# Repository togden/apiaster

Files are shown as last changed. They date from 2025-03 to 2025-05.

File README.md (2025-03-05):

# Apiaster

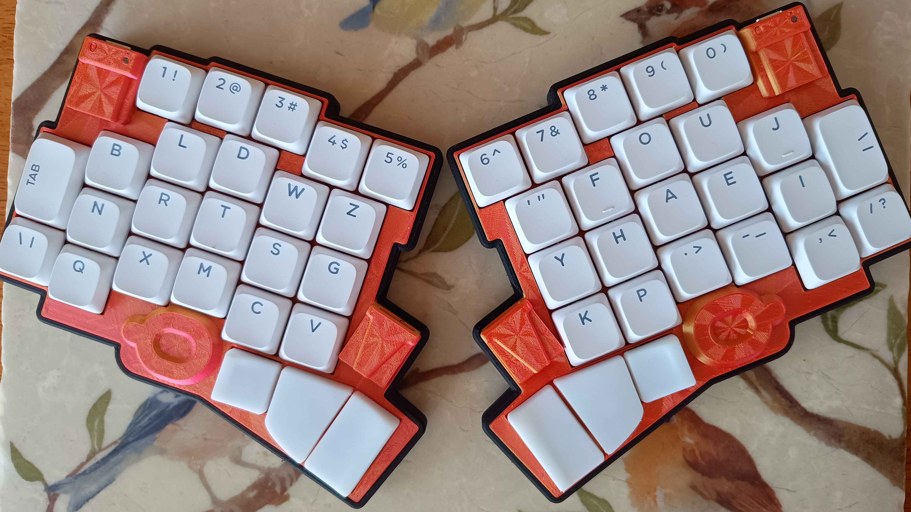
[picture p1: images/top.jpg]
Apiaster Title Image

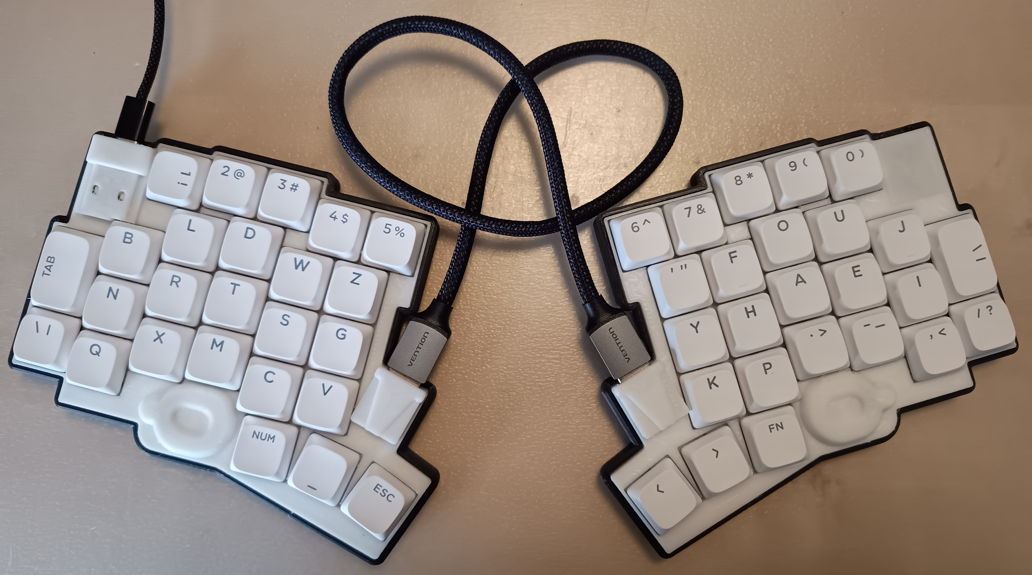
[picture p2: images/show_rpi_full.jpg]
Image of Apiaster in white and black, using rp2040-zero connected by cable.

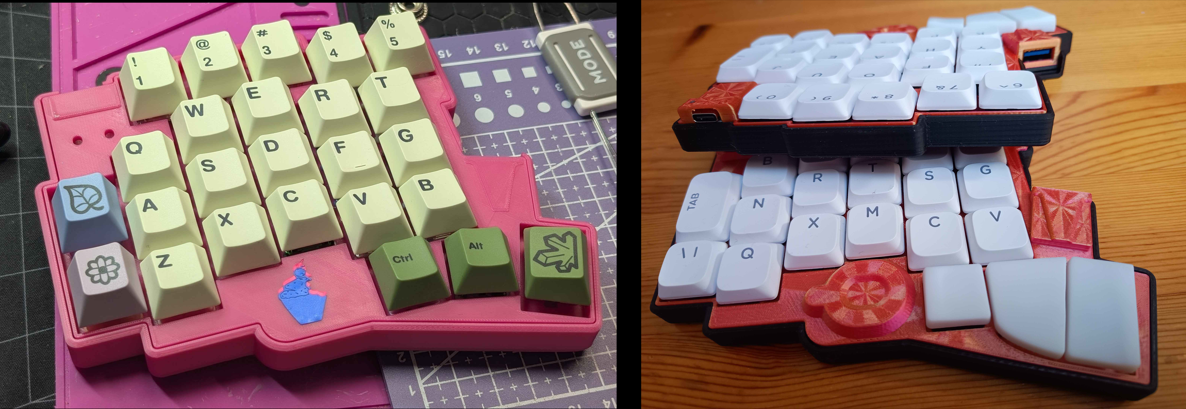
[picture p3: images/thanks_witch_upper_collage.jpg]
Two images side by side, one with Apiaster from the top, the other MX thanks to Witch

Apiaster is a 50-key split keyboard with both an MX and a Kailh choc (v1 & v2) version. It is designed with price and flexibility in mind. The Apiaster is named after the [European bee-eater](https://en.wikipedia.org/wiki/European_bee-eater). Apiaster runs [ZMK firmware](https://zmk.dev/), with the customisation of keymaps, layers, and behaviors allowing it to output every key present in a 108-key 100% keyboard *and more*. **In its most basic form, Apiaster can be built for a total of $36.35 in parts, not including shipping/tariffs/customs or tooling. A version costing $39.11 can be "upgraded" with additional features such as Bluetooth over time.**

# Motivation

There are a number of reasons why someone might be interested in a split, column-staggered[^1] keyboard such as the Apiaster. Most commonly, ergonomics and comfort. Ergonomics is something that tends to be specific to each individual though, making selecting such a keyboard difficult. Both individuals lost for choice and individuals who have amassed a collection of three or more keyboards in the search for their perfect ergonomic experience are not uncommon to see.

Apiaster was designed with flexibility in mind, in particular:
1. The thumb cluster can be snapped off and moved. The case is generated from a script, allowing it to be moved to most reasonable locations (as long as it doesn't collide with the rest of the PCB).
2. The optional choice of reduced inner keys, reducing the strain on the index fingers by avoiding some particularly uncomfortable keys (B and N in a QWERTY layout).
3. The optional choice of an [alternative thumb cluster](https://github.com/Nick-Munnich/ripple-thumb-keycaps) I designed, which brings the thumb keys closer together than would be possible with standard keycaps.

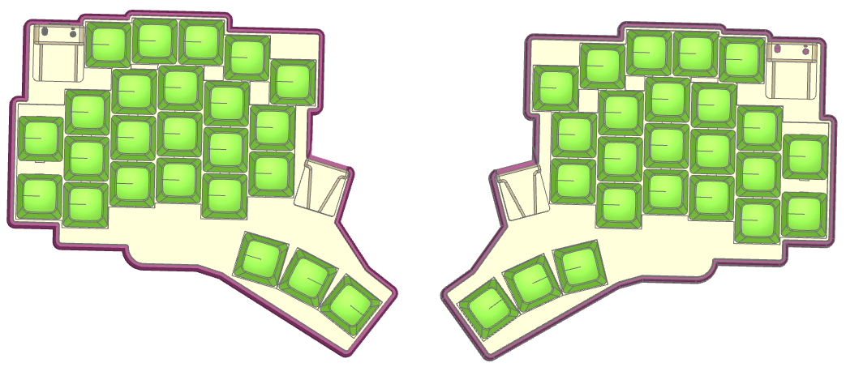
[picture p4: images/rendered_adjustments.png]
Image of a rendered case with adjustments
|  | 
|:--:| 
| *Render showing some of these adjustments* |

This extra flexibility allows individuals to tune the Apiaster to their liking, either providing them with a suitable "endgame" or allowing them to narrow down what specific layout they want quicker. 

## Price

Cost is one of the biggest barriers to entry for ergo-split keyboards. A set of keycaps and switches alone costs more than a cheap basic membrane keyboard. Commercial offerings tend to be either expensive or unreliable. To reduce this barrier to entry, Apiaster is flexible once more:

1. The MCU can be a single rp2040-zero (around 2-3$) with both halves connected via a wire, a single Seeed Studio XIAO (either rp2040 or nrf52840, the latter of which allows the keyboard to have BLE), or a pair of Seeed Studio XIAO nRF52840's (Fully wireless keyboard, no wire between halves).

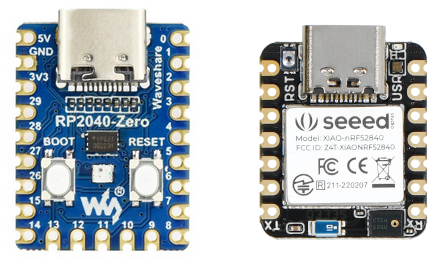
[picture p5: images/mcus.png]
mcu options
|  | 
|:--:| 
| *RP2040-Zero on the left, XIAO nRF52840 on the right* |

3. There are options for both MX and Choc switches, albeit with different PCBs. MX switches are high profile and cheap, with lots of options. Choc switches are low profile and pricier.

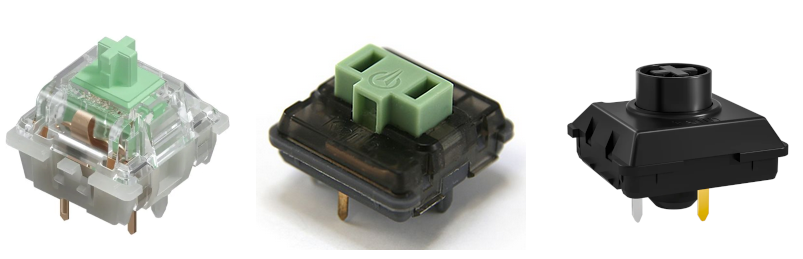
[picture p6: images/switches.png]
switch options
|  | 
|:--:| 
| *MX (18mm), Choc v1 (10.6mm), Choc v2 (12mm) in that order.* |

4. The PCB itself is designed to be reversible, reducing ordering costs from PCB manufacturers (these have a min order number of 5 PCBs).
5. Apiaster can be powered (on wireless) via either a LiPo battery (more capacity, difficult to source reliably) or from a rechargeable coin cell battery

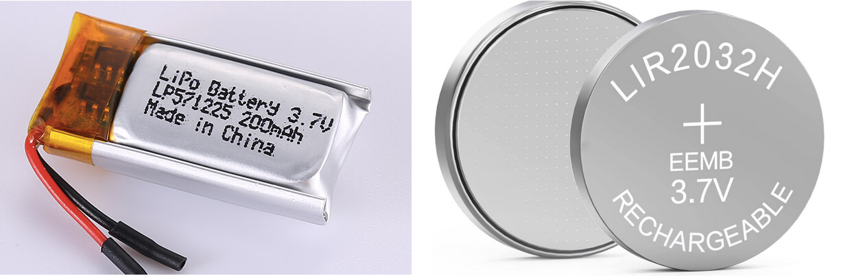
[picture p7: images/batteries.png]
battery options
|  | 
|:--:| 
| *LiPo on the left, coin cell on the right. The ordering guide informs you of dimensional constraints for a LiPo battery.* |

## Mouse

With a split-ergo keyboard, reduced mouse usage is common, and some go so far as to build a pointing device such as a trackball or a trackpad into their keyboard. In theory, Apiaster *should* also have this capability (on the right hand side only, when used via Bluetooth only). However, this is currently untested and lacks case adjustments as I do not have the hardware to implement and test such a pointing device. 

[^1]: The number row is also row-staggered, this will be discussed in the next section.

# Ergonomics

Keyboard ergonomics is a complex topic. There is a lack of research in the particular topic of how beneficial a split keyboard actually is, despite plenty of individuals claiming their benefits - it is simply difficult to get the necessary participants and dedication to such a research study. Moreover, everything in the body is linked - some may find it more beneficial to get a more suitable chair, or a desk at a different height.

Without going into too much detail, I want to provide a brief overview of what is now commonly agreed upon, and how some of the design decisions of this keyboard were made as a consequence. A read of [this page](https://ergonomictrends.com/proper-ergonomic-typing-posture-at-computer/) can be a good introduction to some good typing habits.

## Why Split

There are multiple benefits to a fully split keyboard, i.e. one that consists of two completely separated halves. The obvious intuitive reason is that you can dedicate one half to each hand, but let's explore the rabbit hole a bit, shall we? 

For long-term comfortable typing, a [neutral wrist position](https://ergonomictrends.com/types-of-wrist-movements-and-injuries/) is preferred. Not a *perfectly* neutral position, at least not for most people, but a comfortably neutral position. 

Your shoulders are on the side of your torso. If your keyboard is directly in front of you and you try to place your hands in line with your keyboard, then you cause ulnar deviation. Most people who learned to type naturally, i.e. were not taught bad typing habits in a classroom, will have their hands at an angle to their keyboard when at rest. It makes sense to angle the keys that each hand uses towards them, to bring the keyboard in line with your arm and hand movement, encouraging a neutral wrist.

While there exist many designs for unibody keyboards which have angles between halves dedicated to each hand (e.g. the [ffkb](https://fingerpunch.xyz/product/faux-fox-keyboard-v4/)), a true split allows for every individual to angle the halves at whichever angle and distance is most comfortable to them. The angle at which you want your keyboard and how close you want the halves to be is related to how far away you want it from your torso.

### Tenting

Fully split keyboards also allow for [tenting](https://www.reddit.com/r/ErgoMechKeyboards/comments/1i2s2or/magsafe_is_the_most_underrated_tenting_solution/). This prevents over rotation of the wrist, allowing for a more neutral position. The ideal tenting angle is again, dependant on the individual and the distance at which the keyboard is from the user. 

### Other Benefits

Aside from the above ergonomic benefits, split keyboards are also just nice to have for some other, miscellaneous reasons. They free up space in the middle of your desk, perfect for a mug or a glass or especially for a cat that used to love lying on your keyboard. You can [mount the halves to your armrests](https://www.reddit.com/r/ErgoMechKeyboards/comments/1if5sec/magsafe_accessories_as_keyboard_mount_on/). While gaming, you can put away one half and free up a ton of room for your mouse. 

## Staggered Keys

Most keyboards commonly used today are "row staggered".

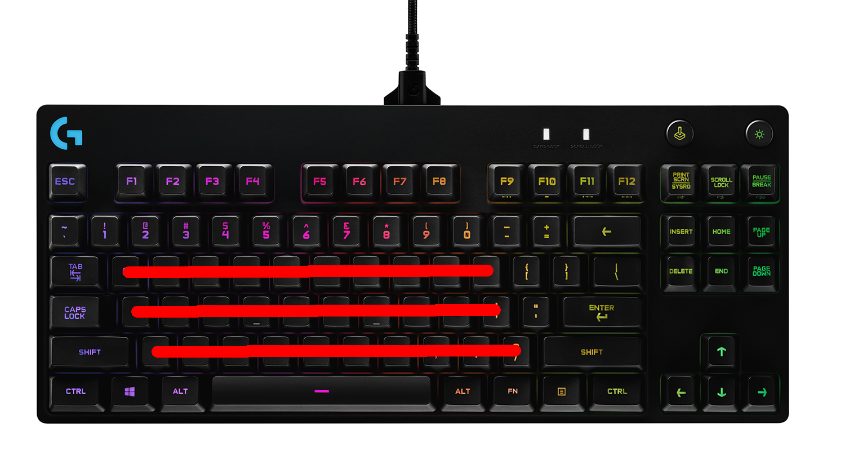
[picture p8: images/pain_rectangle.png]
Row Staggered Keyboard


Row stagger originated with typewriters due to mechanical reasons, and it's just sort of....stayed. Row stagger forces your fingers to move from side to side as they move up and down rows. We can do better.

Column staggered keyboards stagger the keys in line with your fingers.
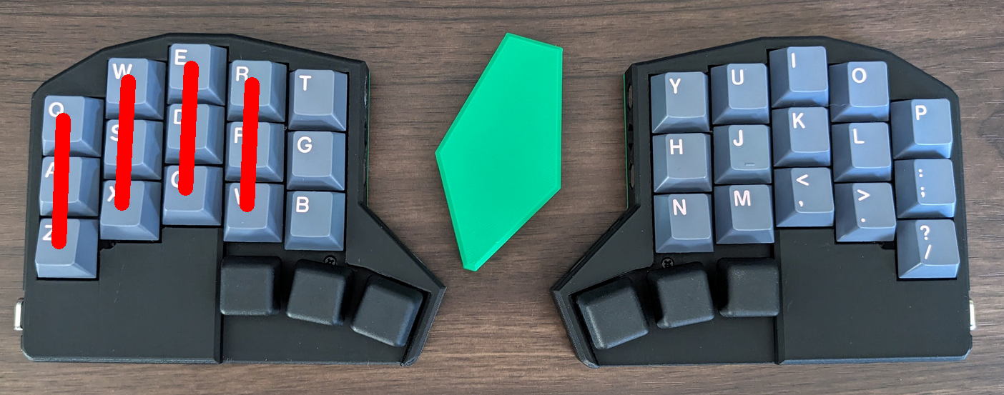
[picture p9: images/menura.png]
Menura
|| 
|:--:| 
| *[Menura](https://github.com/rmuraglia/menura-kb) Keyboard* |

The amount of stagger that is ideal is generally related to the lengths of each finger. Apiaster's stagger is not as mild as the [corne](https://github.com/foostan/crkbd), nor is it as extreme as the [ferris](https://github.com/foostan/crkbd). The ring finger stagger is slightly less than that of the index, making it more suitable for those whose ring finger is longer than their index, at the cost of being less suitable towards those with the opposite.

Some keyboards also introduce what is known as "splay", where the columns are no longer parallel to one another, but splay outwards. This is because for most people, our fingers will naturally splay outwards to some degree as they are stretched. 

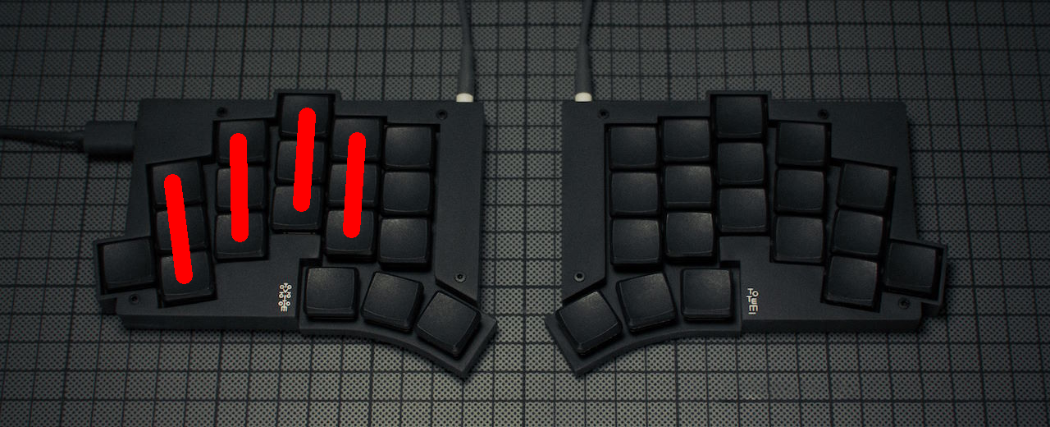
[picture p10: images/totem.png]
Totem
|| 
|:--:| 
| *[Totem](https://github.com/GEIGEIGEIST/TOTEM) Keyboard* |

### Apiaster

Apiaster features column stagger, but it also features a row staggered number row. The inclusion of a number row was desirable primarily because:

1. It is a less extreme drop in keys, making the keyboard more approachable. 
2. A number row is *highly* desirable for gaming. The key count and key positions of Apiaster were selected to be *just above* what I consider to be the minimum keycount desirable for gaming with one hand on the keyboard and the other on the mouse (My personal minimum is 23 keys, dropping one of the outer pinkies and one key from the inner index column).
3. I believe some occasional stretching of the fingers can be beneficial *if* that stretching is in line with the finger's natural path.

The number row was row staggered in addition to being column staggered for two reasons:

1. The pinky being so small for most people, if the number 1 was in line with the column your hand would have to move to reach it (or you would just be pressing it with your ring finger). The outermost upper pinky key is a more suitable place for a fourth pinky than in line with the column.
2. By row staggering the number row, it naturally somewhat imitates finger splay, but only when the fingers are further extended. This is when the splay becomes more obvious for most.

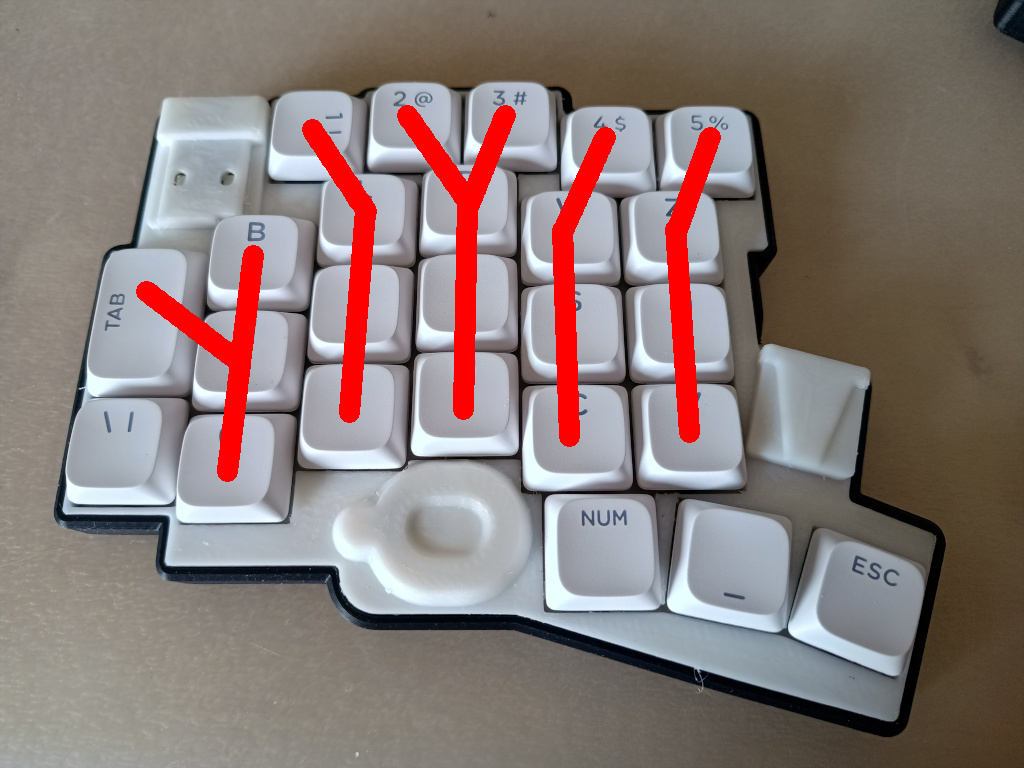
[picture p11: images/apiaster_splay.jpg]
Apiaster's Splay


The specific values chosen for the row stagger also allow the ring and index finger to hit the 2 and 3 without issues, and it happens to closely match the relative stagger of the number row when fingers are resting on WASD on a standard QWERTY keyboard. (Gaming on this keyboard would use the keys labeled DRTS in place of WASD, though the positions matter, not the keyboard layout).

## Thumbs

Thumbs are underused massively with standard keyboards. Ergonomic keyboards will commonly take advantage of their split nature to offer a thumb cluster with more keys than just one.

The thumb cluster is the most difficult part of the keyboard to get right. Variations in hand size, thumb flexibility, etc. can cause wide variations in preferred hand positions. Compare the [corne]() to the [cheapino](https://github.com/tompi/cheapino) for example. The ability of the Apiaster to move the thumb cluster is very advantageous in this respect. There are still some points I wish to touch upon, though.

1. Tucking thumbs under your palm is generally seen as uncomfortable by most. Putting your thumb in line with your index finger is usually the most "inner" position that is still comfortable. Apiaster's minimum is slightly more outer than this.
2. Thumbs move in an arc, not up and down. Hence thumb clusters should do the same. 
3. The thumb cluster is generally recommended to be on the same plane (or a plane parallel to) the other keys. Otherwise you run an increased risk of [De Quervain Syndrome](https://en.wikipedia.org/wiki/De_Quervain_syndrome), a problem that is ever more likely to occur due to increased smartphone usage.
4. Minimizing movement of the thumb along the "fan" is seen as desirable. 

Apiaster is capable of having both standard keycaps at an 11 degree angle between keys or it can use a [thumb cluster](https://github.com/Nick-Munnich/ripple-thumb-keycaps) I designed, which has its own advantages (read the README in the repo) but unfortunately needs to be 3D printed.

# Ordering and Build Guide

The ordering and build guide for this keyboard can be found [here](docs/_START_HERE.md).

# Firmware

Firmware can be found [here](https://github.com/Nick-Munnich/zmk-apiaster-module).

# Acknowledgements and References

There are a number of people and projects which served as inspiration and motivation for this project. Thank you to Sadwitch and tompi (cheapino) for serving as initial inspiration for the concept, and again to Sadwitch for helping with various little bits. Thank you to carrefinho for letting me use some of their art. Thank you to petejohanson and bravekarma for all of their work on ZMK. Thank you to hookykb for writing the charlieplex driver, which this keyboard relies upon. Thank you to quappo for providing the inspiration for the inner key column alternative keys. Finally, thank you to sadekbaroudi and all of the lovely folks on the fingerpunch Discord. Keep being awesome.

Certain images in this README were taken from the websites of manufacturers or vendors and can be taken down on request.

# License

This README and any images which I have the rights to are licensed under CC BY-NC-SA. Individual parts of this repo are licensed under different terms which can be found under their corresponding folders. In particular:

- The hardware stuff found under `/pcb` is licensed under CERN OHL-S.
- The contents of `/case`, in particular the source code used to generate the case, is licensed under MIT.
- The documentation is licensed under CC BY-NC-SA.

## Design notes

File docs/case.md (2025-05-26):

# Generating The Case

You will be running the case generator via GitHub Actions. To do so, start by forking this repository

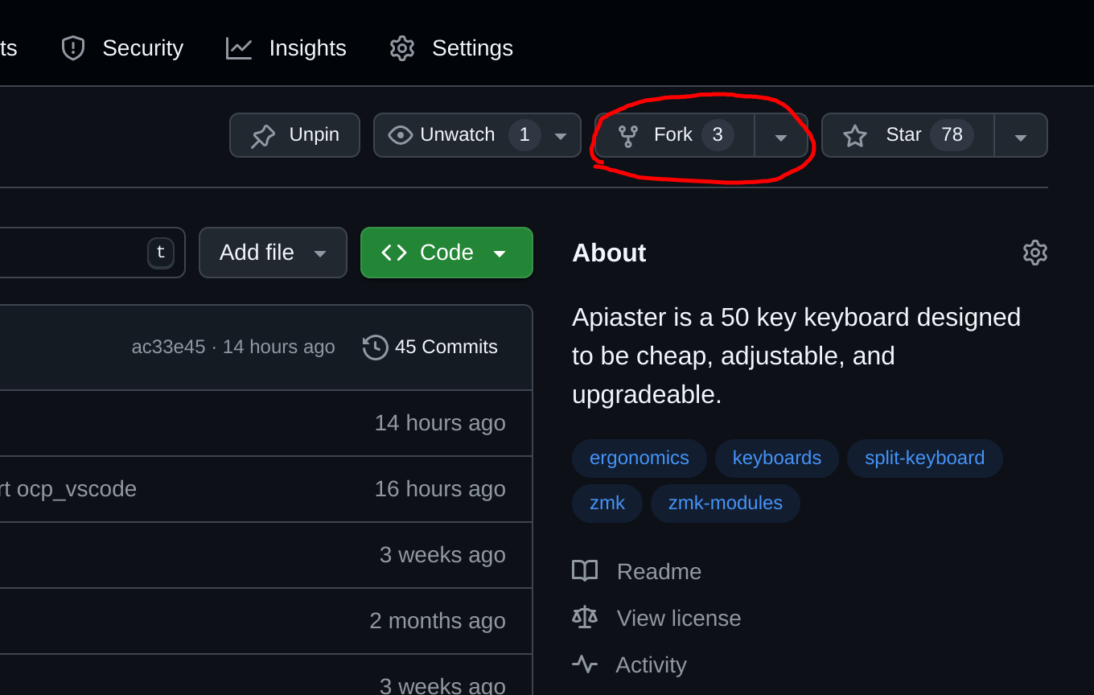
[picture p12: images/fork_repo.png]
Fork the repo


Next, make sure that you have GitHub Actions enabled in your repository. Go to `Settings` and then the Actions (General) category:

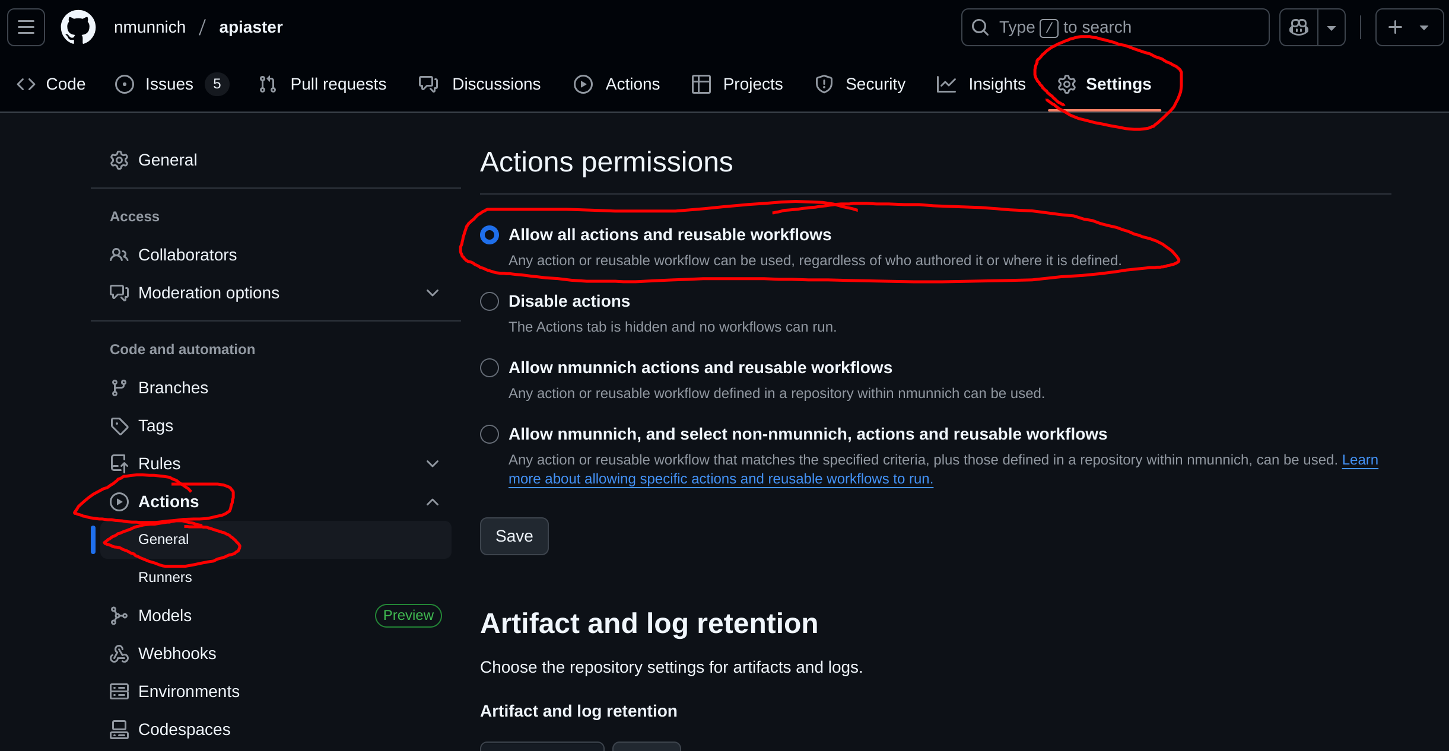
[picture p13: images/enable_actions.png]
Enable GitHub Actions


Make sure "Allow all actions and reusable workflows" is selected (click save!).

Now navigate to the `Actions` tab, and click on the "Make Case" action on the left:

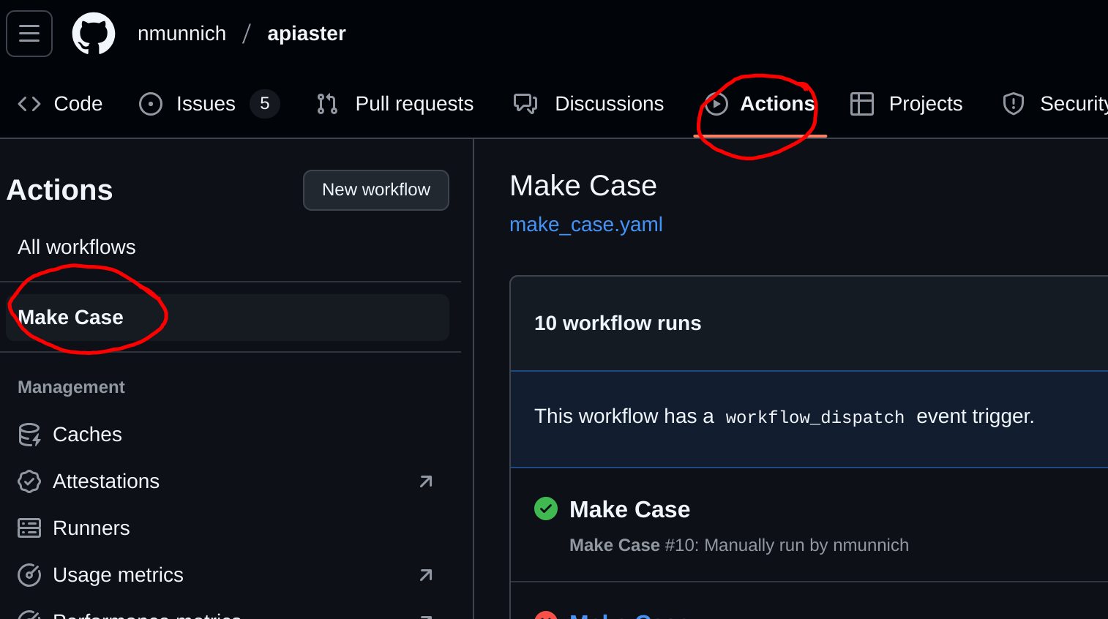
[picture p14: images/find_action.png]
Make Case


You can then click `Run workflow` and adjust any settings you desire, then click `Run workflow` at the bottom.

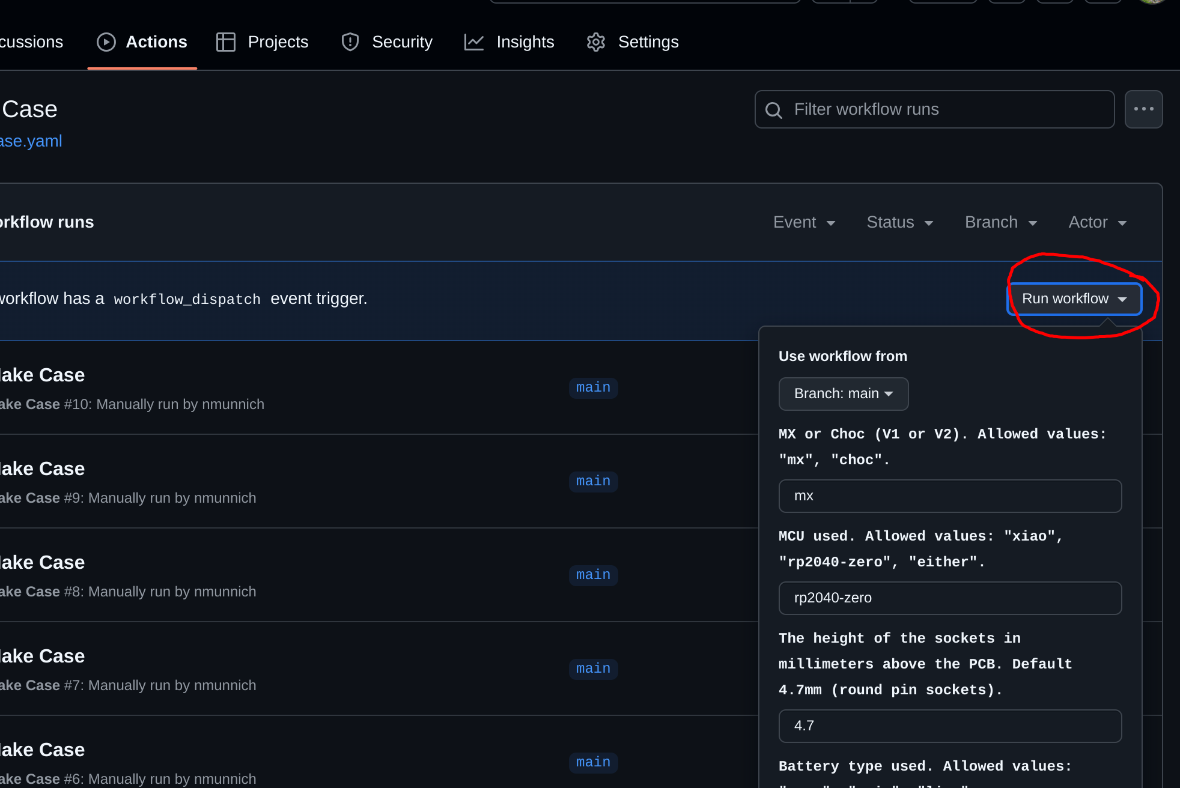
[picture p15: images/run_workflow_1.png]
Run Workflow

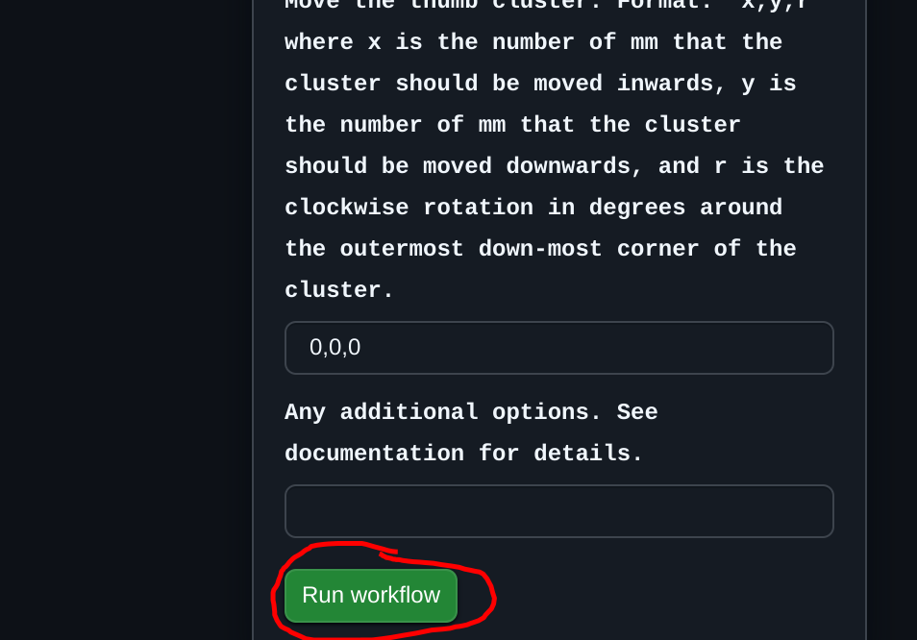
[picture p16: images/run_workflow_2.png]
Run Workflow


After refreshing the page, a new workflow should appear:

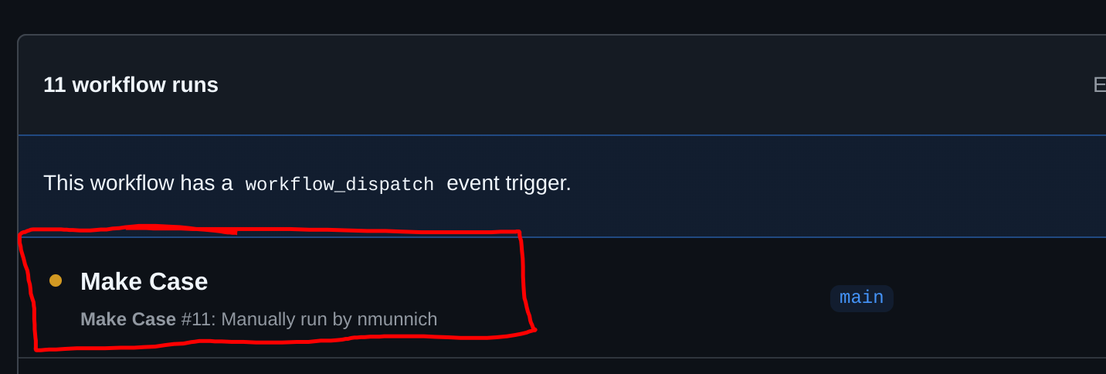
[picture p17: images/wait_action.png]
Wait for action


Click on it, and wait for it to finish running. Once it is done, your case files should appear as an artifact (refresh the page if they don't appear):

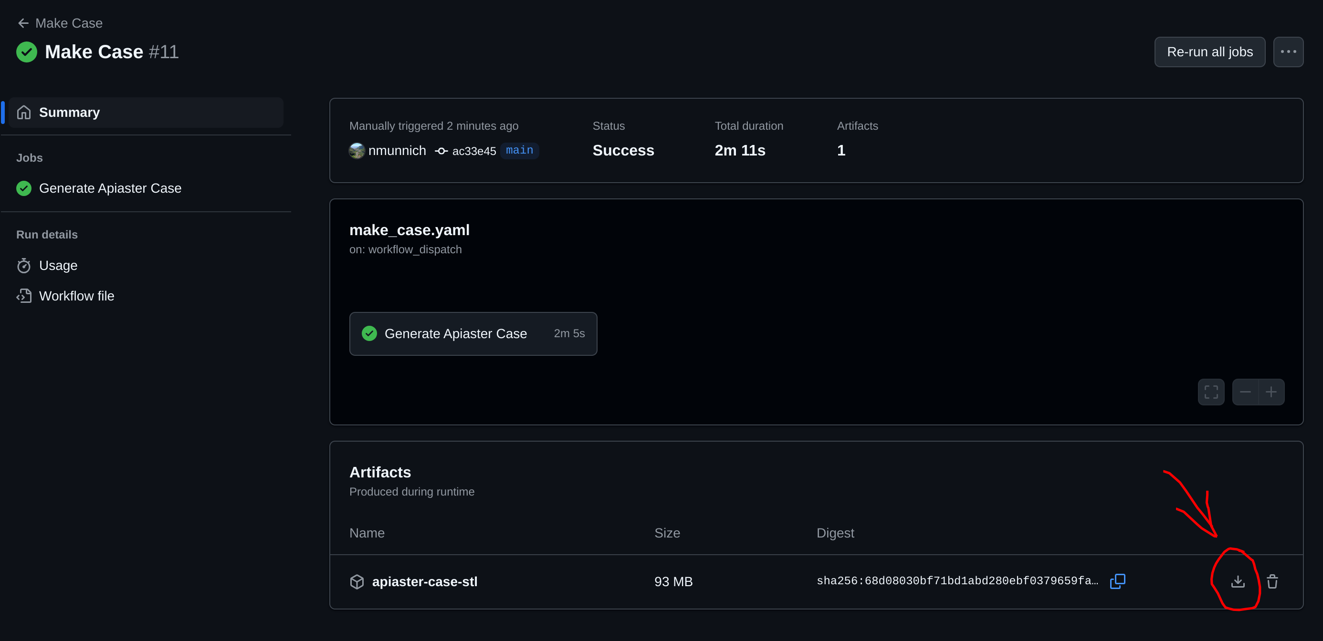
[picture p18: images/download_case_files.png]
Artifact


## Extra Settings

In addition to the settings listed, there are also the following more niche settings which you can apply:

|Command|Options|Default|Description|
|---|---|---|---|
|`--low-case`  |true/false|false| If enabled, this will lower the height of the tray and frame such that they stop at the switch snap-on point. (You may need to expose some components)|
|`--no-usb-a`  |true/false|false|Set this flag if you're using a xiao and there will be no usb-A 3.0 port.|
|`--block-usb` |true/false|false|Set this flag if you're using a xiao and there is a soldered usb-A 3.0 port that you wish to cover up.|
|`--smd-diodes`  |true/false|false| Set this flag if you are using SMD diodes. Will slightly reduce the height of the case. | 
|`--expose` |[{mcu,battery,usb} ...]| none of them| Select components which shouldn't be covered up by the tray. Note that 'battery' only has an effect if 'coin' is selected.|
|`--outer-keys`| {all,upper-1.5u,upper-1u,lower,none}| all|Which outer pinky keys should be enabled. All sets the upper key to 1.5u.|
|`--thumbs` |[{reachy,tucky,middle} ...]| all of them| Select which thumbs to use. |
|`--pinkies` |[{upper,home,lower} ...]|all of them| Select which pinky keys to use. Default all.|

Apply these by inputting them into the `Additional Options` field. They should be space-separated. Booleans like `--low-case` do not need an additional argument. For example:

```
--low-case --expose mcu --thumbs reachy --thumbs tucky
```

# Building The Case

Once you have the case of your choice, follow the [case assembly guide](./build-guide/case.md).

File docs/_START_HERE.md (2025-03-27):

# Ordering And Build Guide

Due to the amount of choice that this keyboard gives you, the ordering and build guides are built up a bit like a flow chart. You'll make some decisions, one by one, and then you'll be given a shopping list at the end.

# Choice #1: Switch Type

First, you will need to choose whether you want to build your Apiaster with MX or Choc switches. 

**You will need a total of 50 switches for a full keyboard, but valid builds exist for [reduced key counts](). If your desired switch is sold in packs of 45, or in both packs of 30 and 10, have a look and see if you would prefer one of the reduced key count designs.**

| Switch Type | Notes | Height |
|----|---- |----|
| MX | Cheap, lots of choice (feel, sound, weight, tactileness). Taller, actuation point is further from the resting state. |18mm |
| Choc V1| More expensive, less choice (but still very good choices available). Needs special keycaps, most of which are smaller than the spacing of the Apiaster. Shorter, actuation point is close to the resting state. | 10.6mm |
| Choc V2| Still pricy, but a bit cheaper than the nicest V1 switches while having similar quality of feel. MX stem, so can use cheaper low profile MX switches. Still short, but not *as* short as Choc V1. Typically heavier weight switches compared to V1. | 12mm |

Picking a switch can be an ordeal due to the sheer amount of choice. *You can always switch out switches within both of these types, but you will not be able to switch from one to the other.*

## MX
For MX switches, [ThereminGoat](https://github.com/ThereminGoat/switch-scores) is well known for reviewing switches. If you don't have any experience with MX switches, my personal recommendation is to pick something cheap that is tactile with a weight of around 35-50g. [kbd.news](https://kbd.news/) also has a [switch comparison tool](https://kbd.news/switch/MX-5-pins) which might come in helpful here.

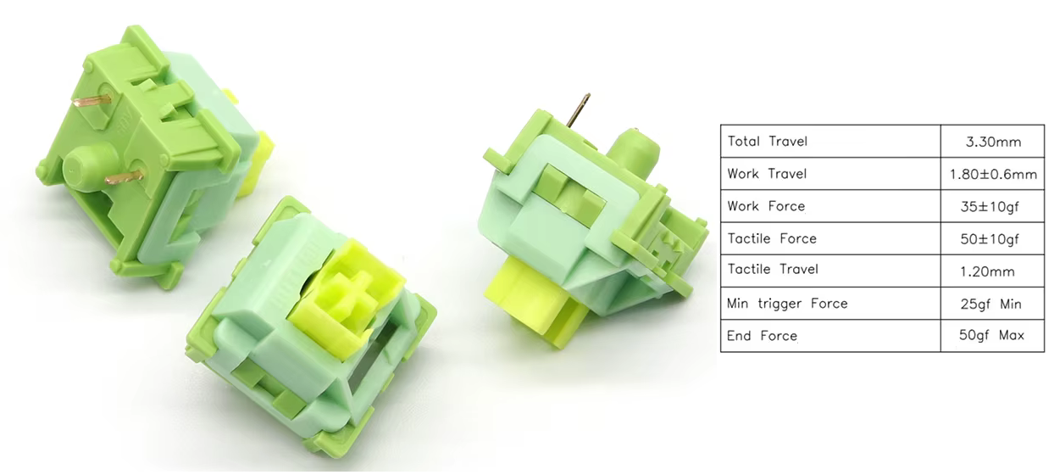
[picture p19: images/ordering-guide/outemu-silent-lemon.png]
Outemu Silent Lemon
|| 
|:--:| 
| *The [Outemu silent lemon v3](https://www.aliexpress.com/item/1005007140434837.html) is an example of such a cheap tactile switch.* |

## Choc V1
For choc switches, you have the choice between V1 and V2. V1 is much more limited in choice for keycaps, but is a bit lower. If you pick V1, then the choice of switch is really quite easy: Get either the ambients or the sunsets from [lowprokb](https://lowprokb.ca/collections/switches) or one of their resellers. If you must get a clicky V1, get the robins. All other options are mediocre when compared with those (though there may be more nicer choc V1 switches on the market in the future). If you want a cheaper choc V1, I would recommend the pro reds to start.

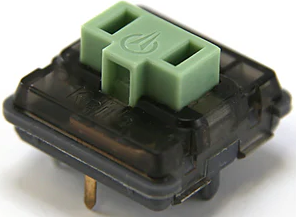
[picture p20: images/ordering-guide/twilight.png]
Twilight
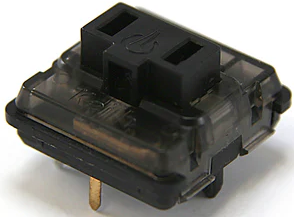
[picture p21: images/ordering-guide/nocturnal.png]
Nocturnal
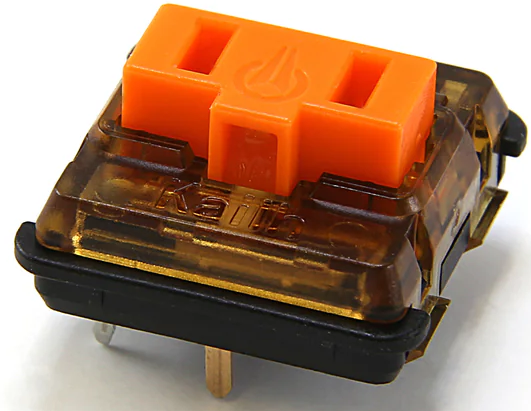
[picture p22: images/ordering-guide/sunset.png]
Sunset
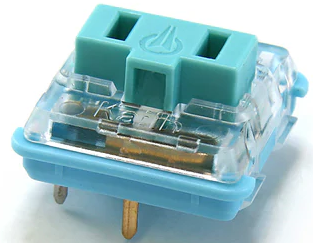
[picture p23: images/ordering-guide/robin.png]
Robin
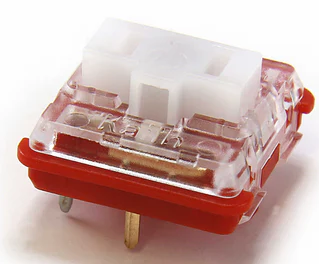
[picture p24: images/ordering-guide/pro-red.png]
Pro Red
| | | | | |
| :--: | :--: | :--: | :--: | :--: |
| *Ambient Twilight, 35g weight* | *Ambient Nocturnal, 20g weight* | *Sunset Tactile, 40g weight* | *Clicky Robins* |*Pro Reds* |

All of the above can be obtained from [lowprokb](https://lowprokb.ca/collections/switches). I would suggest going through their international vendors list if you want one of their specialised switches (ambients or sunsets). For the others, you may find them cheaper in one of the vendors listed on [kbd.news](https://kbd.news/vendors/switch), or on Aliexpress.

## Choc V2

For choc V2, get these:

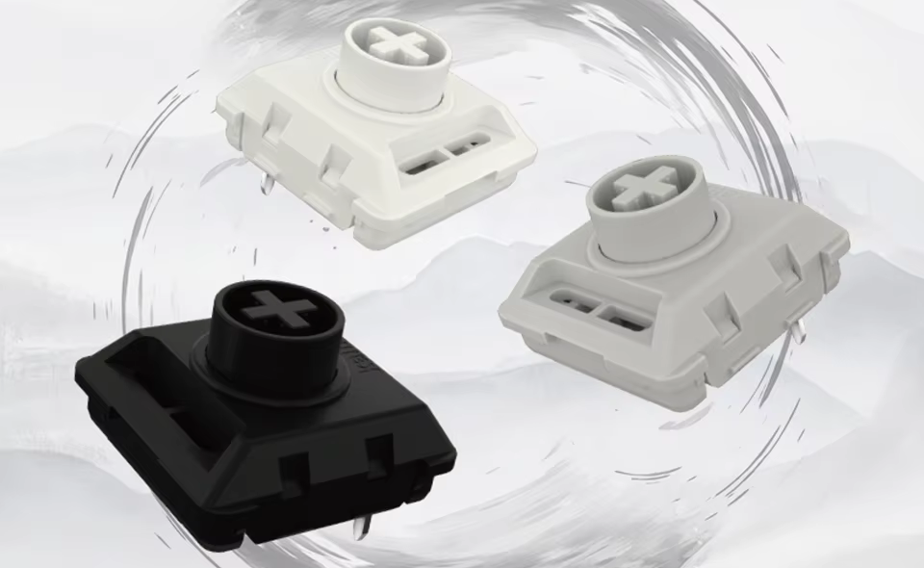
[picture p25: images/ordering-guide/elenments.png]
Kailh Choc V2 Elenments Series
|| 
|:--:| 
| *[Kailh Choc V2 Elenments Series](https://www.aliexpress.us/item/3256807071072267.html)* |

These switches exist under multiple names; if it says "full POM" somewhere, then it's probably one of these. For example, they are also sold by Lofree [here](https://www.lofree.co/collections/switches). They're all very nice, get whichever type (linear/tactile/clicky) you prefer. As with Choc V1, other types of Choc V2 switches are not really worth discussing. I also suspect that Kailh's [four seasons](https://www.aliexpress.us/item/3256807506486516.html) lineup uses the same technology, so you could get those too.

## Keycaps

Whichever switch type you choose will also need suitable keycaps. You should really do some searching yourself, but I'll drop some links here anyway.

 Choc V2 needs low profile MX keycaps. For my build with Choc V2, I chose [a cheap XVX set](https://www.aliexpress.us/item/3256808009058126.html). For MX, any standard MX keycap set will do - [this set](https://www.aliexpress.com/item/1005005386897424.html) seems to be particularly cheap. For choc V1, the most likely (legended, blanks have more choice \& you can 3D print them) sets you'll find are [chosfox](https://www.aliexpress.us/item/3256805104770064.html) or [MBK legends](https://fkcaps.com/keycaps/mbk/legend-40s). Note that both of these have smaller spacing compared to MX, so you'll have larger gaps between your keys as this keyboard is "MX spaced".

 Again, search yourself for the exact set you want. For each option there will be different aesthetics at similar price points, take your time.

# Continue Here

[Click here to continue the guide with MX switches.](./mx-ordering-guide/mcu.md)

[Click here to continue the guide with Choc switches.](./choc-ordering-guide/mcu.md)

# Upgrade Guide

If you have an Apiaster with an RP2040-Zero and you wish to upgrade it to use one or two XIAO nRF52840 controllers, you can follow [this guide](./mcu-upgrade-guide.md) to do so.

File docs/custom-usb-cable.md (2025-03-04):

# Custom Cable

If you want to make a custom USB-A 3.0 cable, you will need:

| Item | Amount | Link | Price (at time of writing) |Notes|
|---|---|---|---|----|
|USB-A 3.0 male ends|2|https://www.aliexpress.us/item/3256803918581184.html or https://www.aliexpress.us/item/2255801079732575.html or https://www.aliexpress.us/item/3256801764065903.html or https://www.aliexpress.us/item/3256805914053747.html or https://www.aliexpress.us/item/3256805068712110.html||Make sure you pick a USB 3.0 version! Also pay attention to shipping costs and lead times.|
|7+ strand wire |Your desired length|https://www.aliexpress.us/item/2255800380986172.html|$1.73 for 2 meters, 8 strands|For a proper USB 3 cable, you need at least 9 strands. The linked cable is 30AWG, which is very thin and unsuitable for USB 3 power transfer. If you wish to use the cable elsewhere, I suggest that you use at least 24AWG. For the linked cable, I recommend 8 strands as this puts the outer diameter at 3.5mm which is not *quite* as thick, but allows compatibility with commonly sized other parts. Note that a *proper* USB 3.0 cable would also include shielding and twisting of the pairs for signal reliability reasons, which is irrelevant for Apiaster.|

You will probably also want:

| Item | Amount | Link | Price (at time of writing) |Notes|
|---|---|---|---|----|
|Heat shrink|2|https://www.aliexpress.us/item/3256805506449553.html|$2.75 for 13mm, 1m, black|The *absolute minimum* inner diameter you can use is 9mm. You need more than a 2:1 shrink ratio. This is to cover up the cable ends.|
| Paracord | cable length|https://www.aliexpress.us/item/2255800708022724.html|$1.22 for 10 ft|Make sure the outer diameter is a bit larger than your cable. For example, for a 3.5mm cable outer diameter, 4mm paracord seems to be suitable.|
|PET expandable sleeving|cable length|https://www.aliexpress.us/item/3256801542457138.html|$0.96 per 5m| The outer diameter of this should be *smaller* than that of the paracord and cable, so that it expands around it to make a nice pattern. 3mm seems good for a 4mm paracord.|

I would then mostly follow [this video](https://www.youtube.com/watch?v=1WgCXG8qcVI), making adjustments for USB-A 3.0 instead of USB-C (and skipping the aviator connector).

## Wiring Diagram

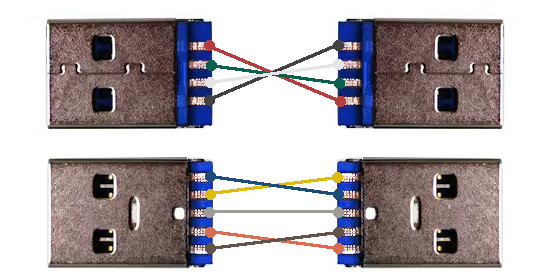
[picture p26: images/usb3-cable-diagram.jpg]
USB A 3.0 Cable Wiring Diagram


Note that unlike USB 2.0, there are some internal wires exchanged. If you have only 7 wires, you can skip the connections marked in red and orange. If you have 8 wires, skip the orange.

# Chop Approach

What you could also always do is take two USB-A 3.0 to USB-C cables with designs that you like, chop them in half, and then reconnect the cables. Either with soldering and heat shrink, or with something fancier like a [9 pin GX16 connector](https://www.aliexpress.us/item/3256805937293382.html).

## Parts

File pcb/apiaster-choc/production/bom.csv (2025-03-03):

Designator | Footprint | Quantity | Value | LCSC Part #
BT1 | BatteryHolder_CR2032_20mm | 1 | Battery_Cell
D1, D10, D11, D12, D13, D14, D15, D16, D17, D18, D19, D2, D20, D21, D22, D23, D24, D25, D3, D4, D5, D6, D7, D8, D9, DI1, DI2, DI3, DI4, DI5 | D-SOD123-DO35-7mm-horizontal-combo_rev | 30 | 1N4148
DS1, DS10, DS2, DS3, DS4, DS5, DS6, DS7, DS8, DS9 | D-SOD123-DO35-7mm-horizontal-combo | 10 | 1N4148
H2, H3, H4, H5, H6, H7 | MountingHole_2.2mm_M2_DIN965_Pad | 6 | MountingHole
J1 | USB3_A_Aliexpress | 1 | USB3_A
J2 | JST_PH_S3B-PH-K_1x03_P2.00mm_Horizontal | 1 | JST PH 3 pin
J3 | BMS 1S | 1 | Conn_01x04_Socket
J4, J5 | PinHeader_1x04_P2.54mm_Vertical | 2 | Thumb Reconnector
J6 | vik-keyboard-connector-vertical | 1 | ~
JP1, JP10, JP12, JP13, JP14, JP15, JP16, JP17, JP18, JP19, JP2, JP21, JP22, JP3, JP4, JP5, JP6, JP7, JP8, JP9 | SolderJumper-2_P1.3mm_Open_RoundedPad1.0x1.5mm | 20 | Jumper_2_Open
N1 | Outline | 1 | Outline
RC0-1|0-6, RC2-1|2-6, RC2-3|2-8, RCA2-1|2-6, RCA2-3|2-8 | Chocv12_reversible_hotswap_no_middle | 5 | SW_Push
RC0-2|0-7, RC0-3|0-8, RC0-4|0-9, RC1-0|1-5, RC1-2|1-7, RC1-3|1-8, RC1-4|1-9, RC2-0|2-5, RC2-4|2-9, RC3-0|3-5, RC3-1|3-6, RC3-2|3-7, RC3-4|3-9, RC4-0|4-5, RC4-1|4-6, RC4-2|4-7, RC4-3|4-8, RC5-0|0-5, RC5-1|5-6, RC5-2|5-7, RC5-3|5-8, RC5-4|5-9, RCA0-1|0-6, RCA5-2|5-7, RCA5-3|5-8 | Chocv12_reversible_hotswap | 25 | SW_Push

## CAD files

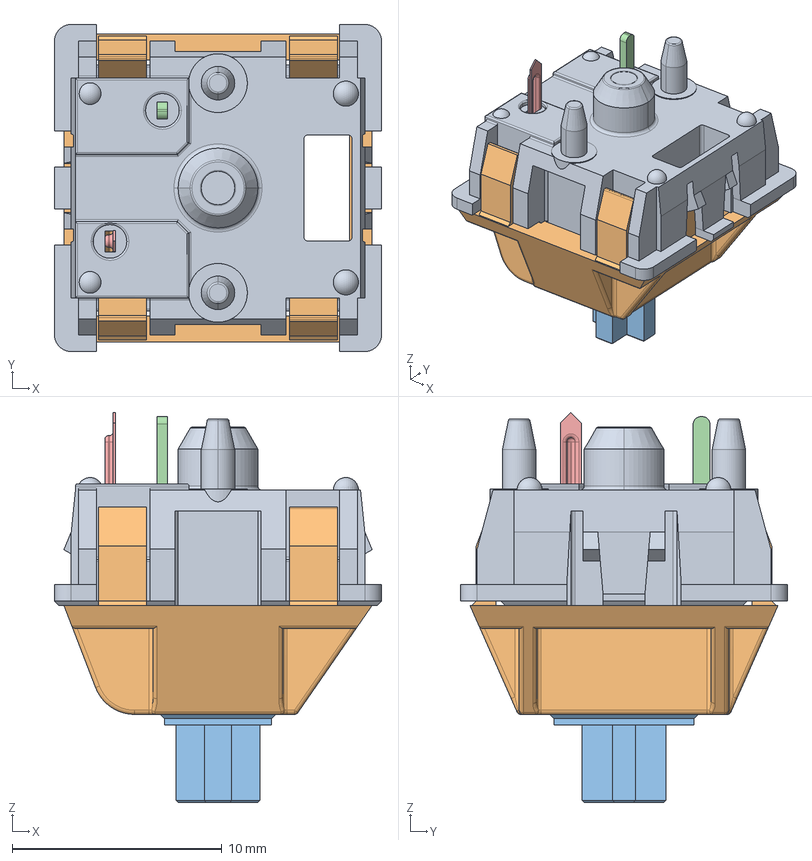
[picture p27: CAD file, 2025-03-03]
case/assets/asm_mx_asm_PCB.step
15.6 x 15.6 x 18.6 mm
MX_DOWN
MX_UP
UP_MX
MX_PIN
MX_SPRING
MX_CLICK

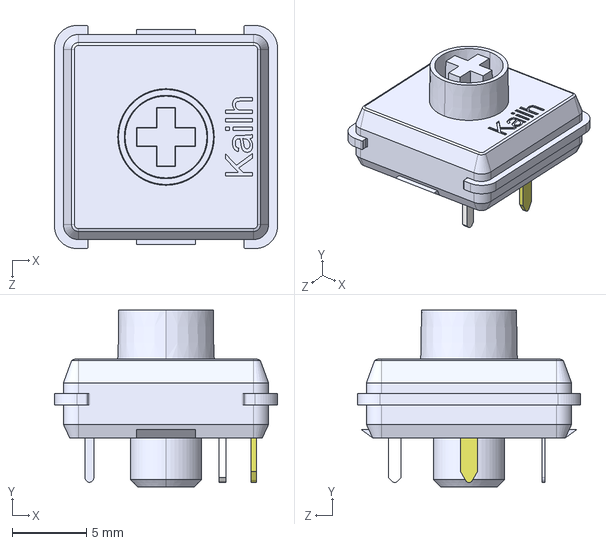
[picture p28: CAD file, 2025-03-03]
case/assets/Kailh_PG1353.STEP
15.0 x 11.9 x 15.0 mm

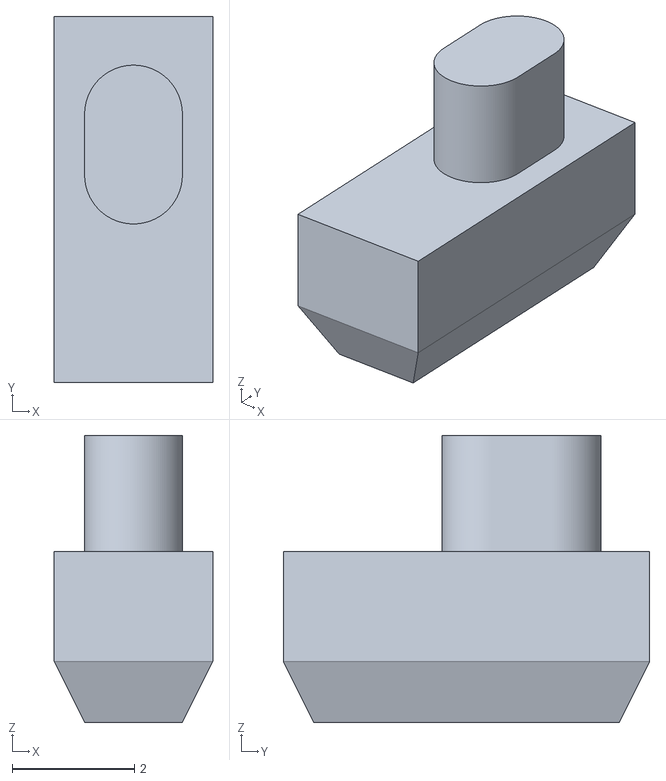
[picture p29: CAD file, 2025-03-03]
case/stl/apiaster-xiao-button.stl
2.60 x 6.00 x 4.70

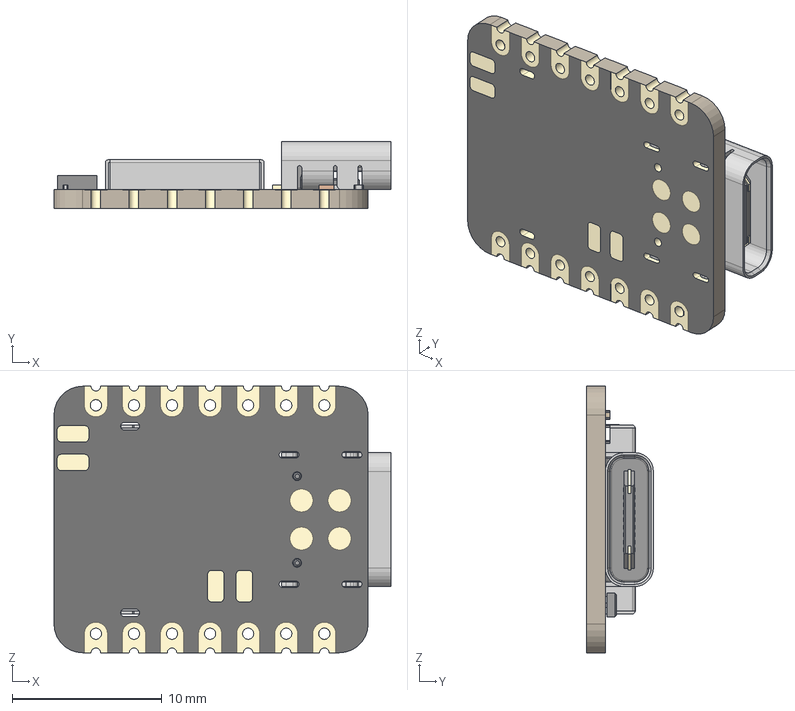
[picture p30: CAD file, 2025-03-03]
case/assets/XIAO-nRF52840 v15.step
22.5 x 4.46 x 17.8 mm
BOSS-EXTRUDE14_8_
BOSS-EXTRUDE7_4_
BOSS-EXTRUDE7_3_
BOSS-EXTRUDE14_4_
BOSS-EXTRUDE14_2_
BOSS-EXTRUDE14_11_
BOSS-EXTRUDE7_7_
BOSS-EXTRUDE14_9_
BOSS-EXTRUDE14_3_
BOSS-EXTRUDE14_7_
MIRROR2
BOSS-EXTRUDE14_5_
BOSS-EXTRUDE14_12_
BOSS-EXTRUDE7_8_
BOSS-EXTRUDE7_1_
BOSS-EXTRUDE14_10_
BOSS-EXTRUDE7_9_
BOSS-EXTRUDE14_6_
BOSS-EXTRUDE14_1_
BOSS-EXTRUDE7_6_
BOSS-EXTRUDE7_2_
CUT-EXTRUDE5
BOSS-EXTRUDE7_5_
Shield
Pins
CAP x 2
ANT1
Silkscreen
CAP 3
LED
USR
2 v1

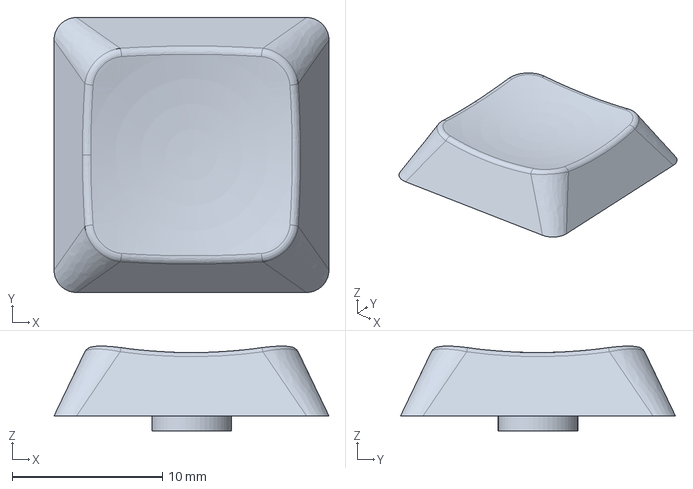
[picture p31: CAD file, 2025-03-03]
case/assets/ols-v1-r3.step
18.3 x 18.3 x 5.65 mm

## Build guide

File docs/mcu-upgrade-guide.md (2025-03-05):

# MCU Upgrade Guide

To upgrade from RP2040-Zero to XIAOs, you'll need to purchase the following items:

## Mandatory Components

| Item | Amount | Link | Price (at time of writing)|Notes|
|---|---|---|---|----|
|XIAO nRF52840|1-3|[Singles](https://www.seeedstudio.com/Seeed-XIAO-BLE-nRF52840-p-5201.html) or  [3-pack](https://www.seeedstudio.com/Seeed-Studio-XIAO-nRF52840-3PCS-p-5921.html)|$9.90 each or $23.39 for 3.| As discussed [here](./mx-ordering-guide/mcu.md). A "sense" version is also sold, but *entirely* unnecessary and just increases the price.|

You will also need batteries. Your choice is between a coin cell battery, and a LiPo:

| Item | Amount | Link | Price (at time of writing)| Type | Notes|
|---|---|---|---|----|----|
|Coin Cell|2|https://www.amazon.de/-/en/LIR2032H-Rechargeable-Battery-Charger-Lithium/dp/B08HRY4QRL|€9.69 for 4|Coin Cell|The code is "LIR2032H", any product with that should be correct unless dubious.|
|LiPo Battery|2|https://www.aliexpress.us/item/2251832478677289.html|€3.93 each|LiPo|A somewhat trustworthy source on Aliexpress. Alleged capacity of 100mAh. Make sure you pick "JST PH 2.0MM" as a connector.|
|LiPo Battery|2|https://bihuade.com/products/37v-140mah-501522-liter-energy-battery-polymer-lithium-ion-li-ion-battery-for-smart-watchblue-toothgps-speaker|€3.93 each|LiPo|The biggest battery that fits in the designed case (fine-tuning may allow a bigger battery). Reliably sourced directly from the manufacturer, but beware the shipping costs. Make sure you pick "JST PH 2.0MM" as a connector.|
|Coin Cell holder|2|https://de.aliexpress.com/item/1005007339595580.html|$1.51 for 10|Coin Cell|Identical product can be found from multiple sources.|
|BMS 1S|2|https://www.aliexpress.com/item/1005007047240735.html|$1.11 for 10|Coin Cell|Needed to protect the coin cell from overcharge/overdischarge (LiPo should have this built in). Identical product can be found from multiple sources.|
|JST PH 2 pin|2|https://de.aliexpress.com/item/1005004955655144.html|$1.12 for 100|LiPo|Pick the right angle version. You can also pick a 3 pin version.|

A *lot* of LiPo battery sources, especially on Aliexpress, are dubious. They tend to claim battery capacities far beyond the actual capacity, often ship lacking proper protection, and there is no way to tell if they might not explode in the future. The shops I linked are ones that I have had good experiences with.

The main advantage of the coin cell is in its availability and reliability. The main advantage of LiPo is in its capacity. Use the [ZMK Power Profiler](https://zmk.dev/power-profiler) to estimate your battery life (LIR2032H has 70mAh):
 * The nice!nano is a decent approximation of the XIAO's battery consumption
 * If you use a cable between halves then do not enable the "split keyboard" toggle
 * If you use a dongle, then both your halves will have "peripheral" levels of power consumption, and the dongle will have "central" levels of power consumption (but should be connected via USB so that's irrelevant).

I recommend the [prospector](https://github.com/carrefinho/prospector) if you want a fancy dongle, but a bare XIAO with nothing attached to it also works.

I expect that you should have leftover pins and sockets from your previous build. If not, buy more of those.

A final, optional item is:

| Item | Amount | Link | Price (at time of writing) |Notes|
|---|---|---|---|----|
|Pogo Pins|2|https://www.aliexpress.us/item/3256805909678051.html|$2.62 for 10| Make sure the leg at the bottom is 0.8mm thick (or thinner), the overall height is at least 5mm, and the height when compressed is at most 4.5mm (assuming round hole sockets, heights may vary depending on your sockets). These are definitely optional, they are used for advanced socketing, but you can easily use a diode leg instead. Only recommended if you are using SMD diodes and don't have any spare wire.|

With all of your parts, you can essentially just remove your RP2040-Zero from your PCB by wedging it out, and then follow the relevant parts of the [build guide](./build-guide/pcb.md). **WARNING: Make sure you desolder the jumpers for the RP2040-Zero *before* you add the XIAO, and remember to solder the XIAO's jumpers on the other side.**

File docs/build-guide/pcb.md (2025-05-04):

# Choc with RP2040-Zero PCB Build Guide

This guide assumes you have already collected all the components you need for your build from the corresponding [ordering list](../choc-ordering-guide/choc-zero.md).

**Before you begin, make sure you know how to solder. [This video](https://www.youtube.com/watch?v=3jAw41LRBxU) serves as a fantastic introduction. You can also read [this guide](https://learn.sparkfun.com/tutorials/how-to-solder-through-hole-soldering/all), but I'm not quite as big a fan of it.**

Pick up two halves of your PCB and lay them on opposite sides so that they mirror each other. At the top, you should see some text "Left Side Front (LSF)" "Right Side Back (RSB)". These are used to help you identify what to solder by looking at the PCB. Treat the sides that are currently facing you as "back", so you should have one "Right Side Back" and one "Left Side Back" facing you. If it helps, you could put a sticker or something on the back sides to help you remember which side is back and which is front (Though this should quickly become obvious once you have some components soldered).

## Step 1: Diodes

We start with the diodes because they are the fiddliest component, so it is easiest to do them while the PCB is clear of components. The images are of through-hole diodes, but SMD diodes are very similar.

### Bending diodes

Begin by bending the legs of the diodes so that they can fit through the holes on each diode position:

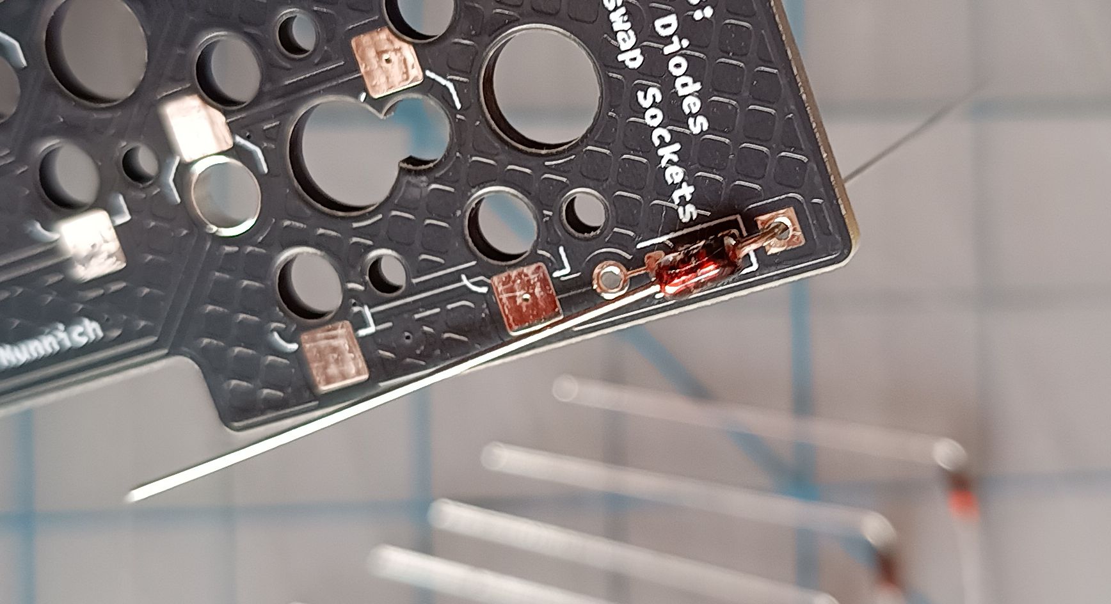
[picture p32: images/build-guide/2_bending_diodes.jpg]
Bending Diodes
| |Bent Diodes |
| :--: | :--: |
| *Use the PCB as a guide* | *Collect them on the side* |

As a reminder, you will need a total of 70 diodes. It makes it easier if you bend them in the same orientation, i.e. bend all the legs on the side with the black stripe.

### Insert diodes

Insert the diodes onto the PCB so that the diode is resting on the **back** sides of both halves. Insert them wherever you see the diode markings on the PCB. **Do not insert any diodes on the front side, all diodes will be on the same side**. Make sure you insert them in the correct orientation, as in the image.

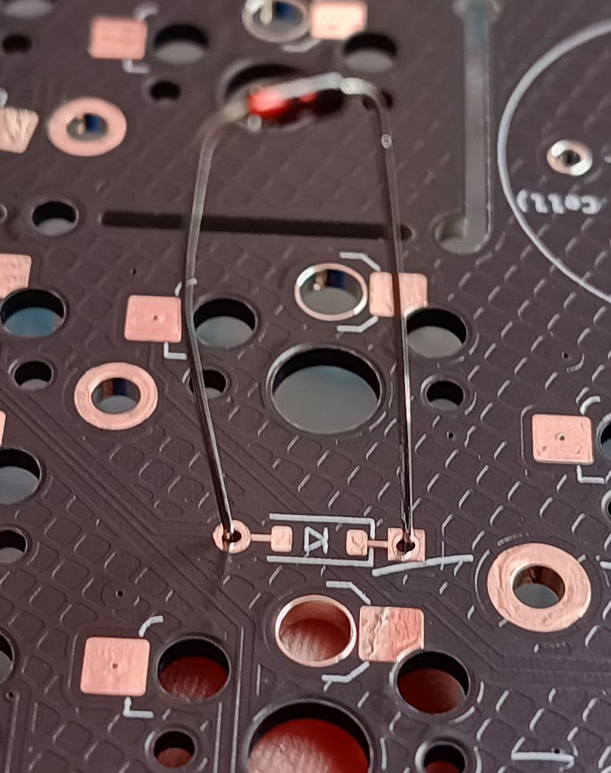
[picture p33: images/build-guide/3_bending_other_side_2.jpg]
Inserting Diodes
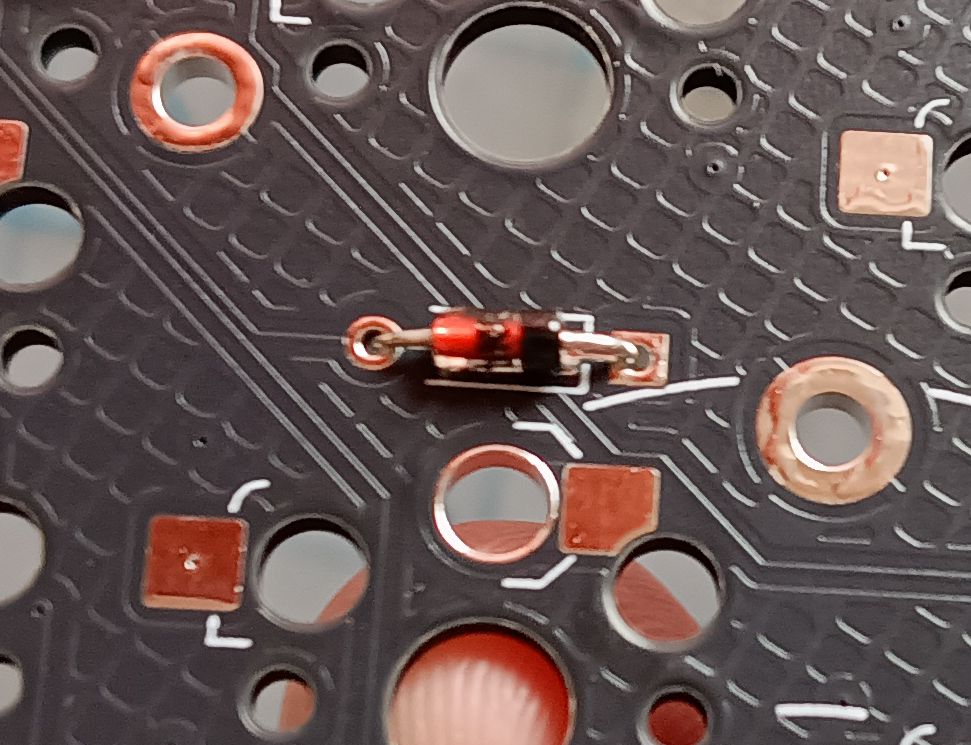
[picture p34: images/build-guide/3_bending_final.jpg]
Inserted Diode
| | |
| :--: | :--: |
| *Bend the other leg as you insert the diode* | *Should look like this when done* |

Once you have the diode inserted, flatten the legs on the other side to hold it in place. 

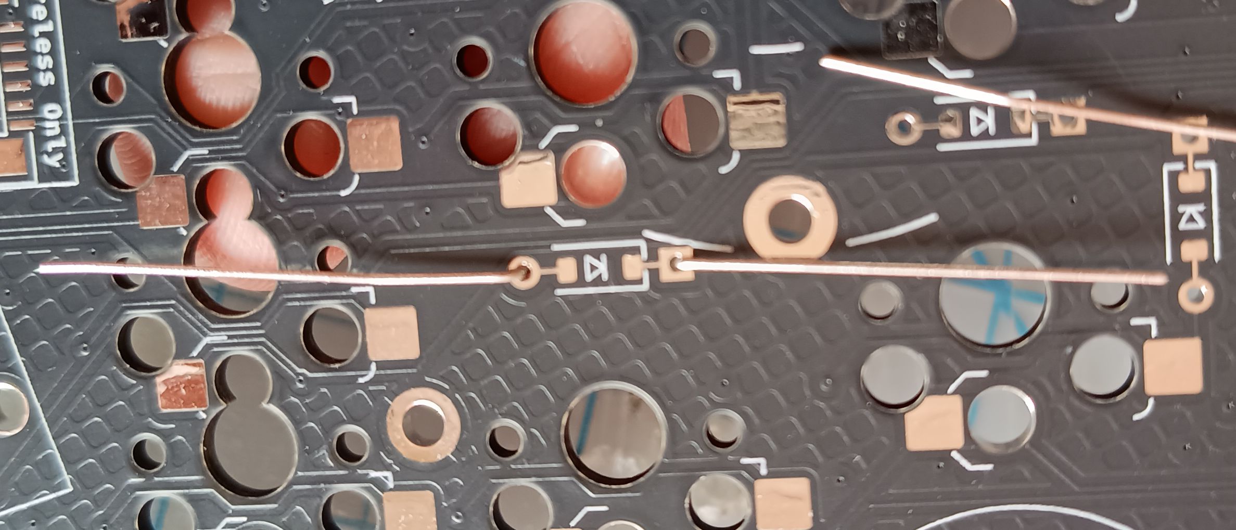
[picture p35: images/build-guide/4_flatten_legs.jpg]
Flattening Legs
| |
| :--: |
| *Take your time!* |

Double-check that the orientation of your diode is correct.

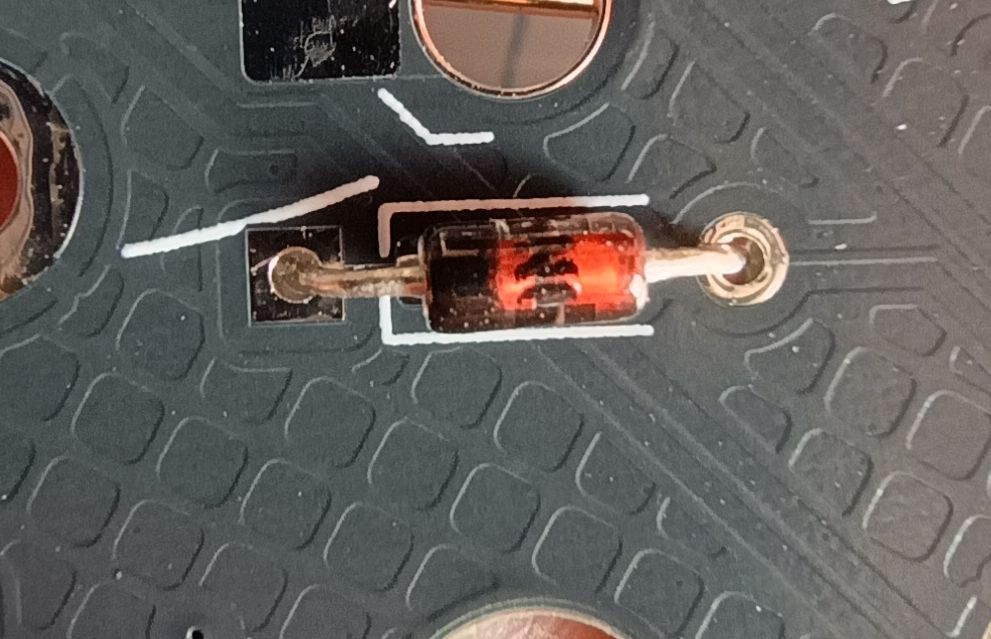
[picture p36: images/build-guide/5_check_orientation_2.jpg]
Diode orientation
| |
| :--: |
| *I like to think of the markings as a water glass and the black line needs to be at the bottom of the glass* |

The PCBs should look like this once you've inserted all the diodes.

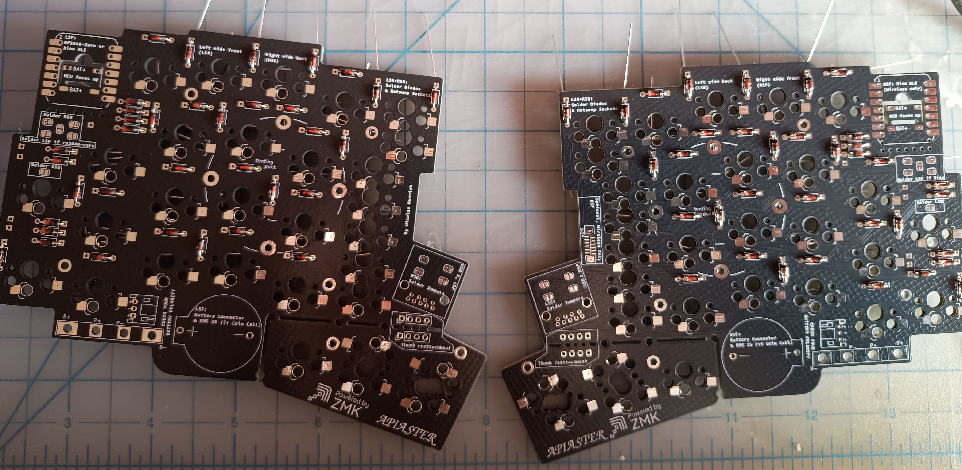
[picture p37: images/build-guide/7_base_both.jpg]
All Diodes Back
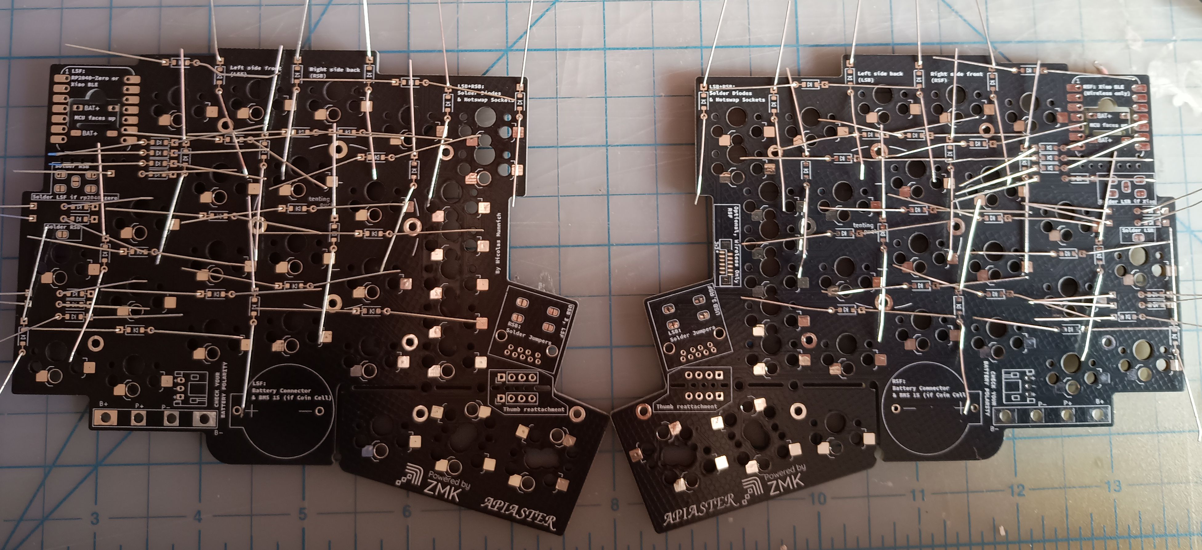
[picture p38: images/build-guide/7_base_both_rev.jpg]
All Diodes Front
| | |
| :--: | :--: |
| *All diodes inserted into the back sides* | *Bent legs on the front sides* |

Orient the PCBs to that the back side of each is facing you, then solder the diodes.

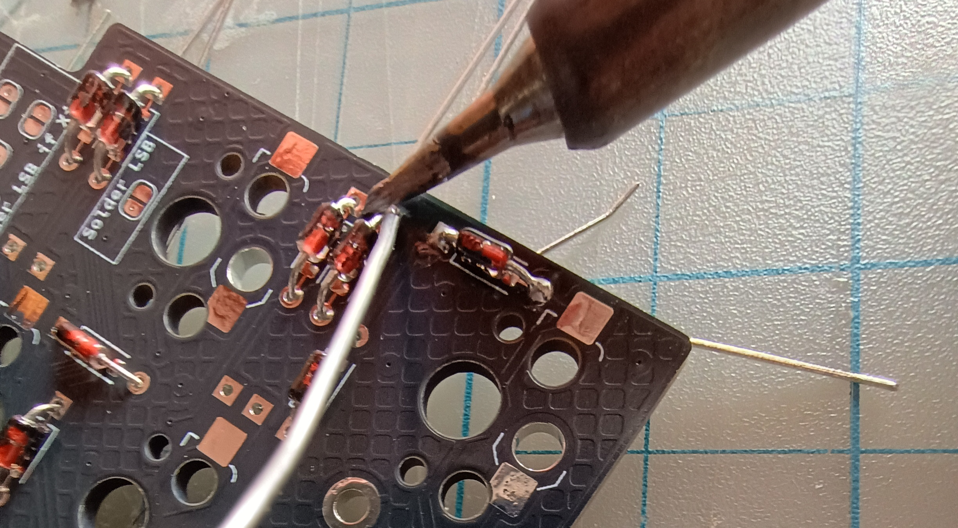
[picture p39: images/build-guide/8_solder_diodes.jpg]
Soldering
| |
| :--: |
| *This wasn't actually me soldering, holding the camera made that too difficult. Use a better orientation when soldering.* |

Finally, use your wire cutters to clip the legs off all the diodes.

|Clipped diodes |
| :--: |
| *I recommend holding something above the wire cutters or wearing eye protection, those legs can jump! Cut as flat as you can without damaging the PCB.* |

## Step 2: Soldering Jumpers

There are a handful of jumpers that you need to solder. 5 on LSF, 5 on LSB, 10 on RSB. On each PCB there should be 5 near the MCU, 4 near the USB, and one near a switch under the MCU.

**WARNING: If you solder the jumpers wrong, then this might damage your MCU when you plug it in. Please doublecheck that you are closing the right ones.**

On the USB-A socket, close *all* the jumpers on the **opposite** side to the USB connector. This should be the **same** side as the diodes and hotswap sockets.

There is a single jumper far under the MCU near a switch with the text "Solder LSB" or "Solder RSB". Solder these on the back sides as stated, the **same** side as the diodes, **opposite** side to the MCU.

Finally, the 5 jumpers for the MCU just underneath it. On the PCB that you have designated as the right hand side, solder the jumpers on the **same** side as the diodes, just like all the other jumpers.

However, on the left side, which side you solder depends on your MCU:

* XIAO: Solder the jumpers on the **same** side as the diodes, just like all the other jumpers.
* RP2040-Zero: Solder the jumpers on the **opposite** side as the diodes, the same side as the switches will be. These are the **only** jumpers which should be soldered on the front side. If you solder these jumpers, do not solder the corresponding jumpers on the back for the XIAO.

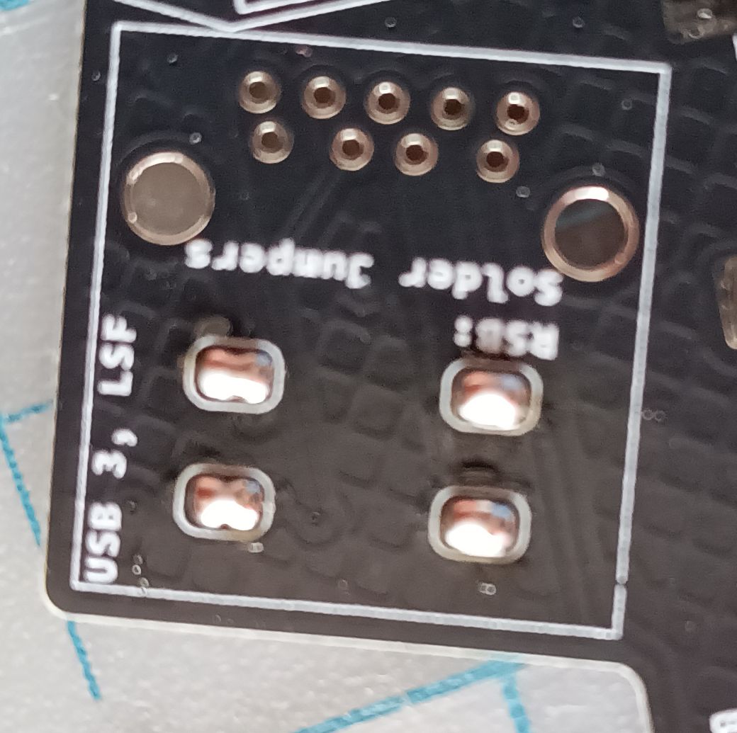
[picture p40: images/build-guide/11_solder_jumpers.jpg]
Solder jumpers
| |
| :--: |
| *Essentially just a blob of solder connecting the two bits. Make sure you're heating both at the same time if you're struggling to get it to bridge. Add flux if it's not smooth.* |

## Step 3: Adding Hotswaps

One by one, place the hotswap sockets and solder them in place. **Note that if you are using choc hotswap sockets, you will need to decide on your inner key positions now, as the hotswaps will otherwise block the switches from being inserted.** Also note that if you only have 50 (or fewer) you should pick and choose which hotswap sockets to solder based on your desired switches. There is no conflict with the thumbs, you can solder all the hotswap sockets there.

|Hotswaps |
| :--: |
| *All the hotswap sockets for the full inner key column and standard 1u thumb cluster. Ignore the bad soldering job, I was unwell at the time. I redid them later on.* |

The "Ripple" thumb cluster uses the hotswap sockets in the "correct" orientation, while the standard 1u sized ones use the "upside down" ones.

Soldering tip: Hold the soldering iron to the side of the socket, touching the pad underneath with the tip. Add a drop of solder to the iron to help with thermal conductivity, then feed the solder **into** the socket. Then, obviously, remove the solder wire, wait for it to settle, then remove the iron.

## USB A Connectors

Skip this step if it doesn't apply to you.

If your choices result in you using a USB A 3.0 connector to connect the halves, then this is what you should solder next. Put it on the *front* side and press it into the holes until it clips into place (this might be a bit fiddly).

Solder all of the pins. You do not need to solder the clips, though you *can* if you wish.

|USB |
| :--: |
| *USB socket, soldered. Note that your closed jumpers should be on the side **opposite** the USB connector.* |

*Disclaimer: I made a minor error in the first revision of the PCB and had to use some bodge wires with the usb connector. The error should be fixed in the current version, but this disclaimer will be kept until that is confirmed.*

## Batteries

Skip this step if using RP2040-Zero.

While inserting the battery will be the *last* step that you do, now is a good time to solder the battery parts.

### Coin Cell

For the coin cell connector, stick the connector through the holes so that the connector is resting on the *front* following the markings on the PCB, then turn it over and solder the connectors.

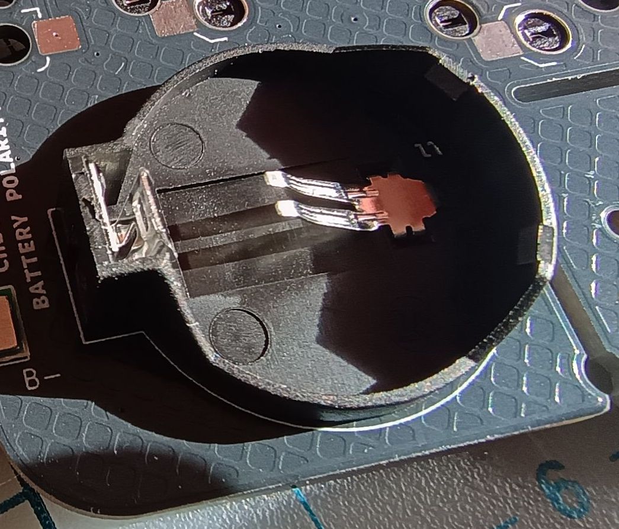
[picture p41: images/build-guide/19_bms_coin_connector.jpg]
Coin Connector
| |
| :--: |
| *Solder the two pins on the other side.* |

There is a decent chance that the connection won't be flush. If this happens, press the connector into the PCB while applying a bit of heat to the pin that's sticking out.

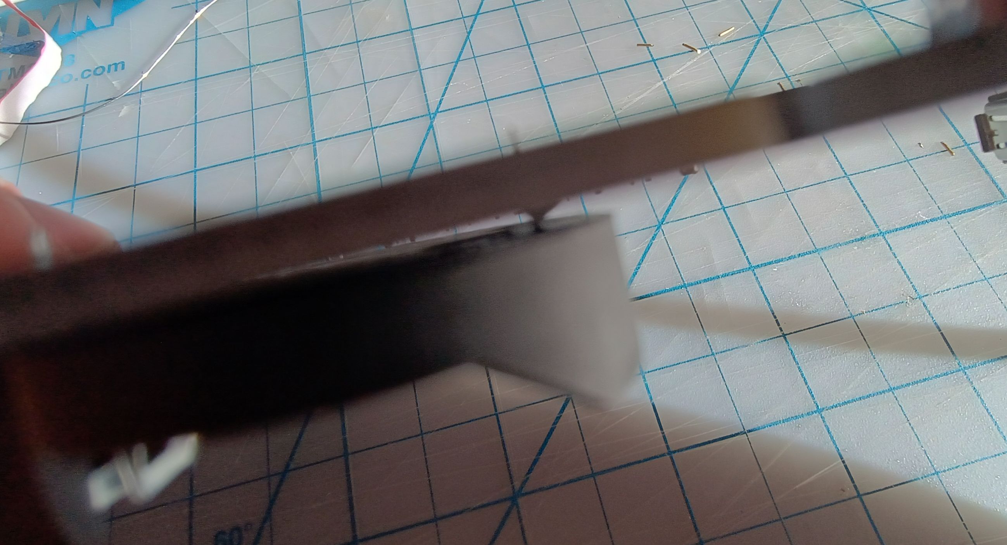
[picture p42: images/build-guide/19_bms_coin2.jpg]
Coin Connector Flush
| |
| :--: |
| *This gap shouldn't be there.* |

You'll then need to solder the BMS 1S battery protection circuit onto the *front* side as well.  **Make sure the text on the PCB matches up with the text on the BMS 1S, B+ to B+, B- to B-, etc.**

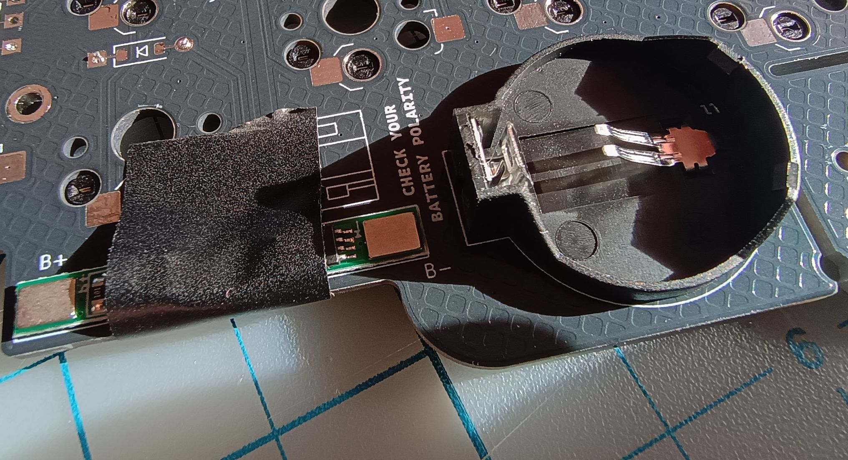
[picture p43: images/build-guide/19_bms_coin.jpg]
BMS 1S
| |
| :--: |
| *I tried doing this with some electrical tape, and it did not work out for me, so I'm recommending crocodile clips or similar be used. Note that my silkscreen for the battery connector in this image is the wrong way around - B+ is the side closest to the coin cell. This was fixed in the published version.* |

Turn the pcb over and feed solder into all the holes to form a good solid connection between PCB and BMS 1S. This is likely the trickiest part of the build, hopefully you'll have had a good amount of practice soldering by now.

### LiPo

For this battery type, you'll want to solder on the JST PH header. Insert it onto the *front* side, making sure that the pins match the orientation of your battery's cables - use a multimeter to confirm the orientation if you're uncertain. If you purchased a 3 pin socket, then you will need to do this when inserting the battery instead. **Reverse polarity is dangerous.**

## Step 5: Multimeter Verification

Take a moment to verify that everything is correct. If you have a multimeter, take it out and put it on continuity mode. 

### Choc:

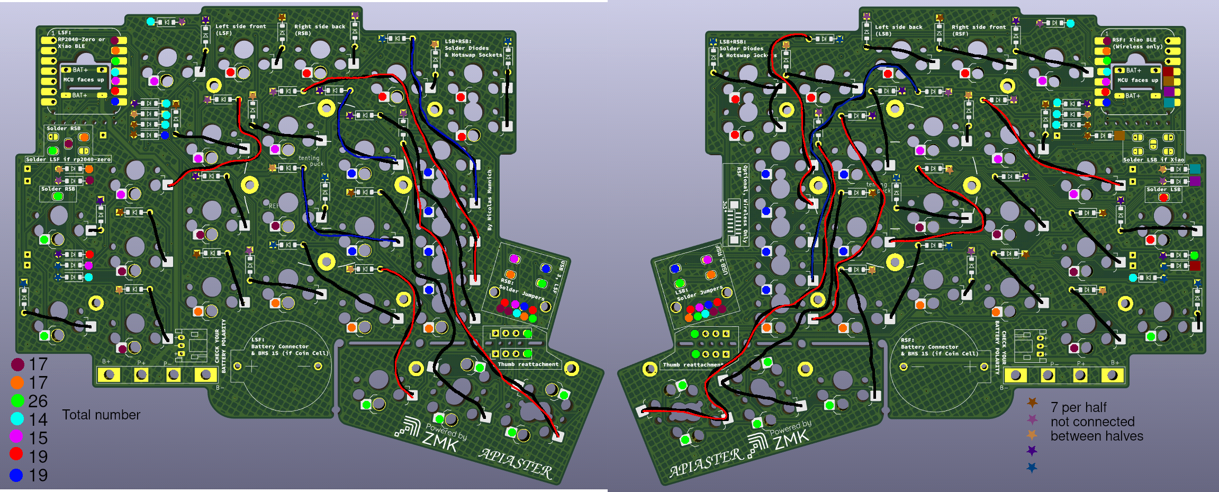
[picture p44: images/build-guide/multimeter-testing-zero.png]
RP2040-Zero Verification
| |
| :--: |
| *Infographic to help verify the connections for the **Choc RP2040-Zero** setup.* |

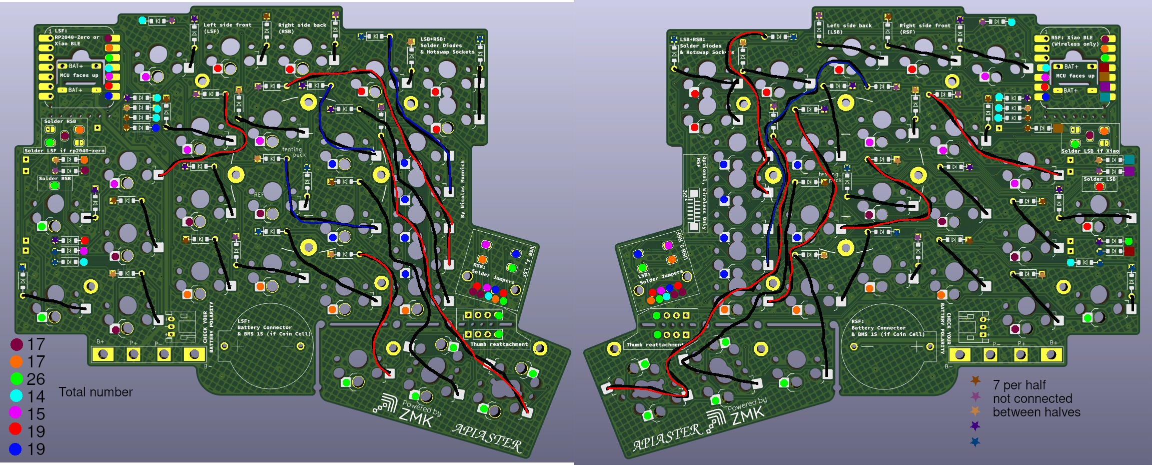
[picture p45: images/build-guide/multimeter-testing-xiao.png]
XIAO nRF52840 Verification
| |
| :--: |
| *Infographic to help verify the connections for the **Choc XIAO nRF52840** setup.* |

### MX:

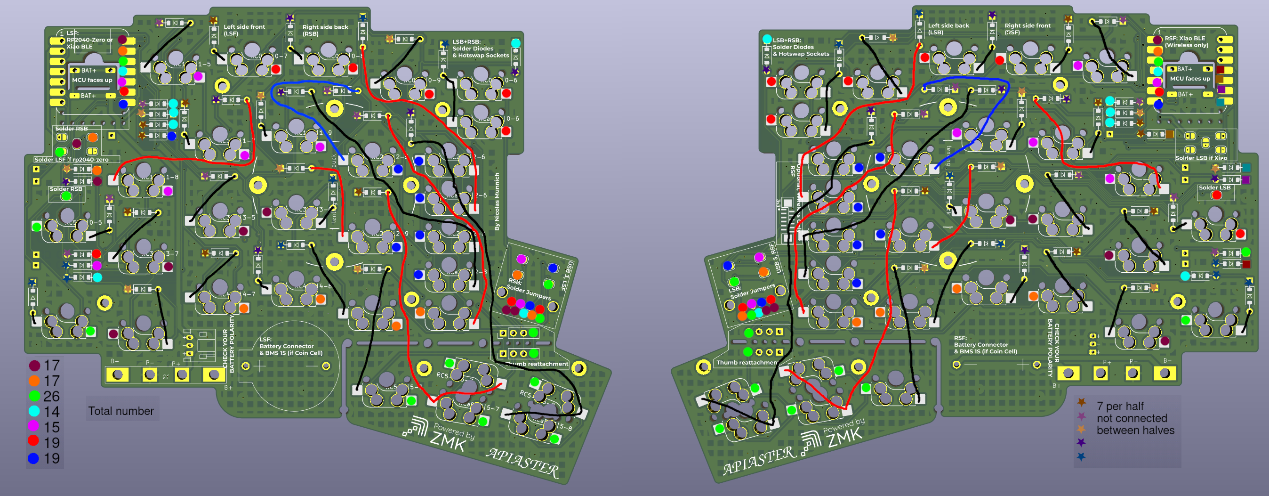
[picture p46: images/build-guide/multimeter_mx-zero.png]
RP2040-Zero Verification
| |
| :--: |
| *Infographic to help verify the connections for the **MX RP2040-Zero** setup.* |

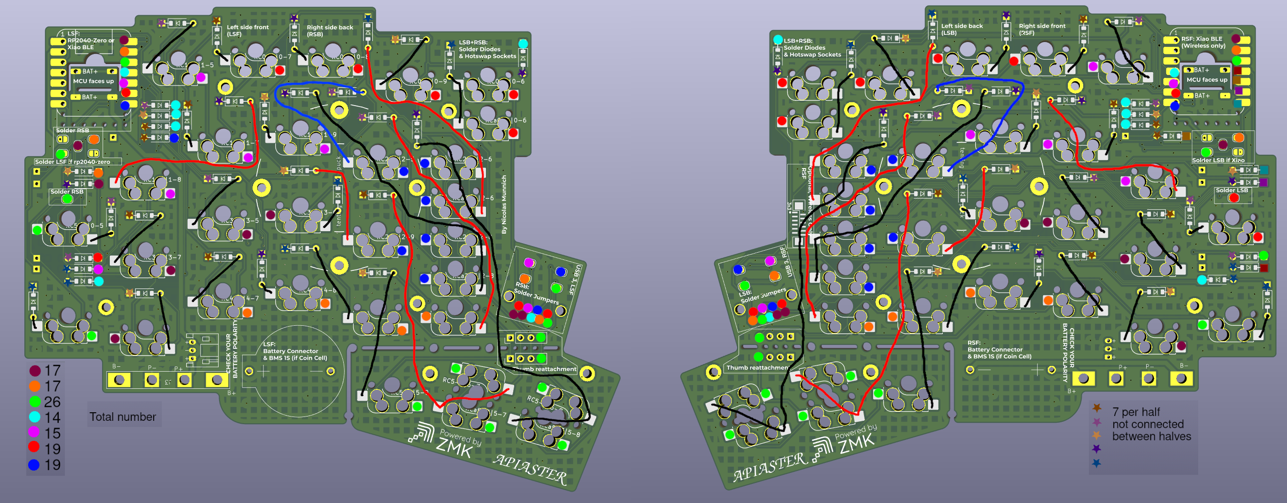
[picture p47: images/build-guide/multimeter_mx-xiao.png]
XIAO nRF52840 Verification
| |
| :--: |
| *Infographic to help verify the connections for the **MX XIAO nRF52840** setup.* |

Plug the USB A 3.0 cable into both halves, and turn it over so that the **back** is facing you. You can then probe continuity according to the above graphic for your choice of MCU - any connections with the same shape and color should have continuity. Probing the battery-related bits can be done using the markings on the PCB directly.

## Step 5: MCU

Next, you'll want to prepare your MCU's sockets. **If you are SMD mounting the MCU, skip to the next step, then solder your MCU on afterwards.** If you haven't already and are using round-hole sockets, use pliers to yank out the pins.

My approach is to use a breadboard to stick the sockets in, then insert the pins into the sockets. Then solder the MCU to the pins, and finally use the MCU as a guide to solder the sockets to the PCB.

An alternative strategy to making sure the sockets are straight which doesn't use a breadboard can be found [here](https://github.com/zzeneg/molekula/blob/main/keyboards/Molekula2/README.md#central).

|breadboard sockets |
| :--: |
| *Insert the sockets into the breadboard, insert the pins and push them down so that they are seated. Some use a line of (electrical) tape over the sockets to prevent any solder from connecting the pin to the socket - do so if you're inexperienced.* |

|insert MCU |
| :--: |
| *Insert your MCU of choice. For the RP2040-Zero, note that **you are only using the topmost 7 pins**.* |

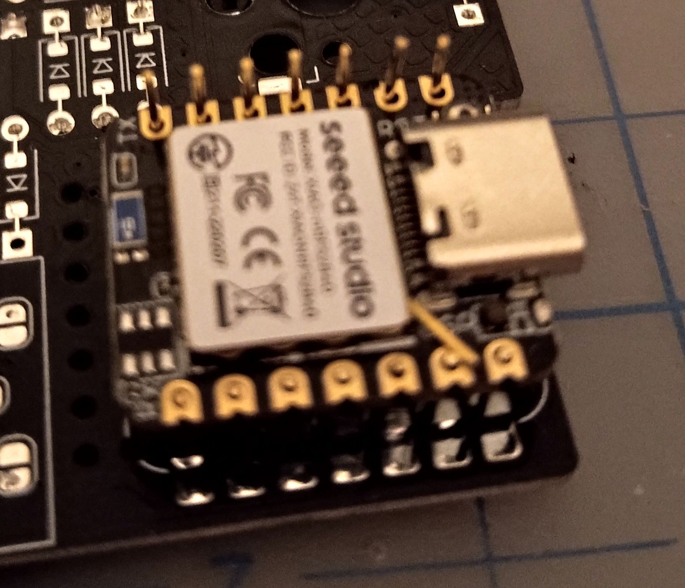
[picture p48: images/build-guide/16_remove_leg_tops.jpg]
clip legs
| |
| :--: |
| *Clip the legs off before soldering. They need to be nice and flat for the case.* |

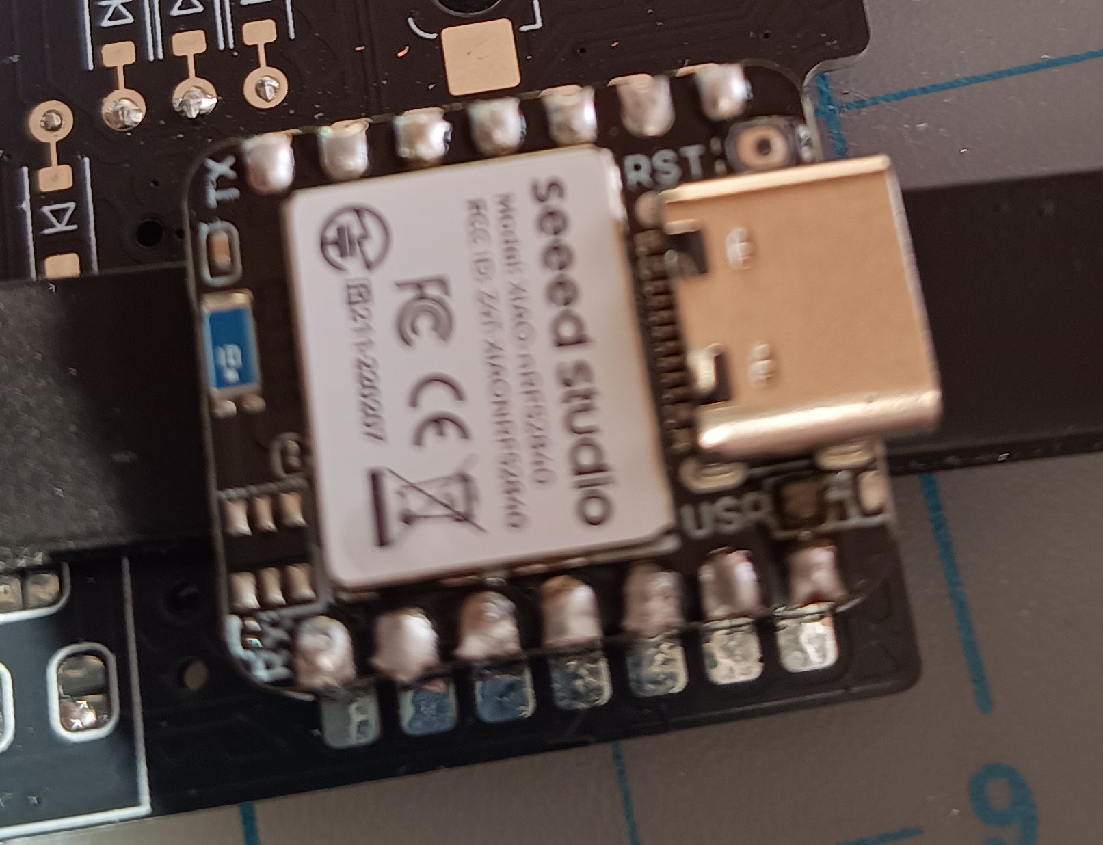
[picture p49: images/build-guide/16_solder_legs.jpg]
solder legs
| |
| :--: |
| *Solder the pins onto the MCU.* |

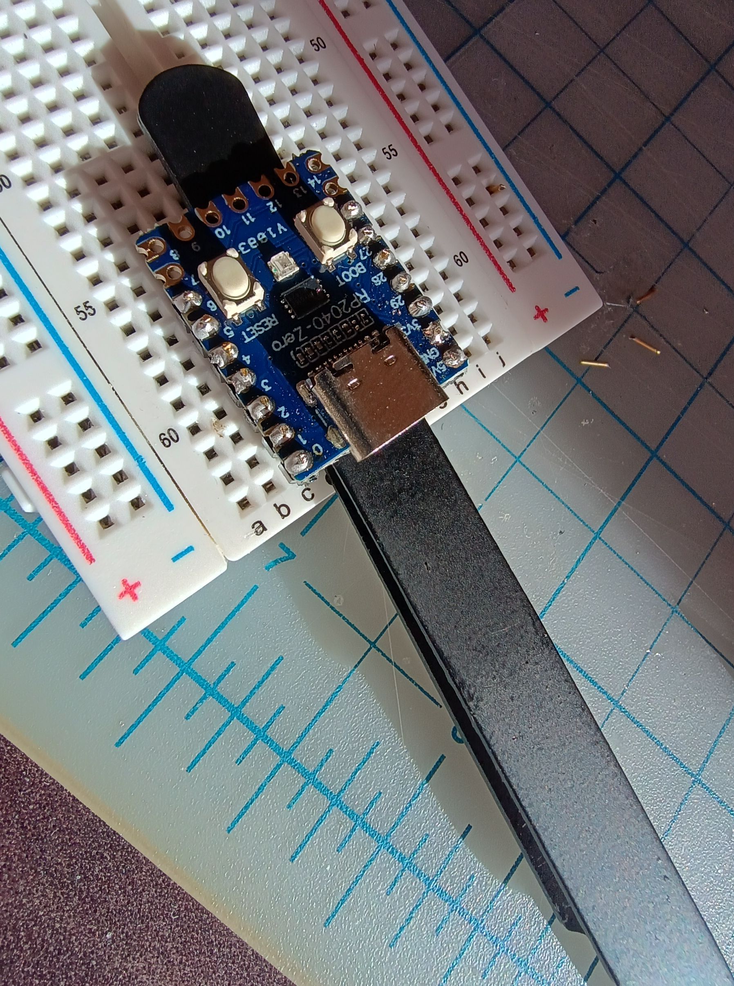
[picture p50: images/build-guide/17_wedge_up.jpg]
remove MCU
| |
| :--: |
| *Use your tweezers or something else to wedge the mcu up and away from the breadboard. Don't worry if the sockets come with, you want them to be on the MCU for now.* |

If you are using the RP2040-Zero, you want to solder the pins and MCU to the **left half only**. Same if you are using a singular XIAO. If you have two (or more) XIAOs, add the MCU to both halves.

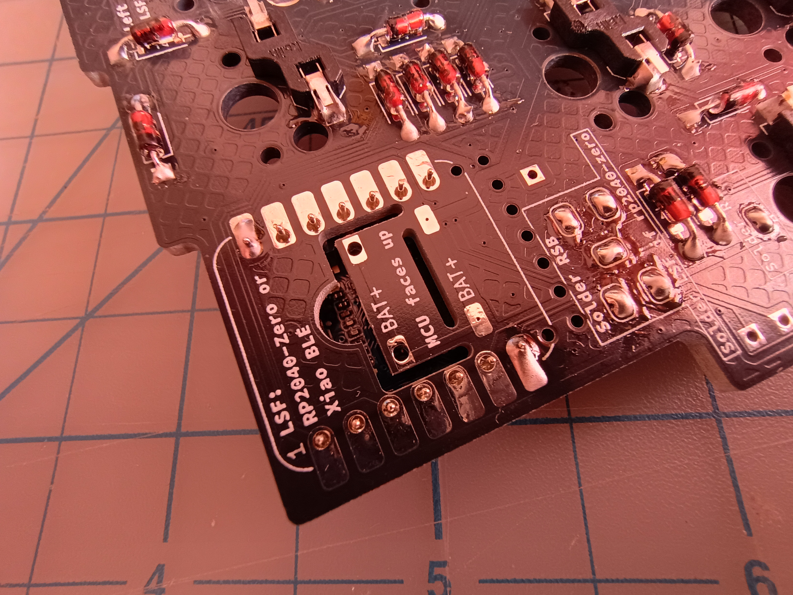
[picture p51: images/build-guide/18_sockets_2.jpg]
| |
| :--: |
| *Insert the sockets into the PCB, using the MCU as a guide, then solder them.* |

## XIAO Battery Connection

The XIAO's B+ pad will need to be connected to the PCB. The B- pad can be ignored, it is already connected through one of the other pins. Begin by removing the XIAO from the socket using the wedging technique again, the female sockets should stay as you soldered them in place.

|solder legs |
| :--: |
| *Should look like this. Obviously skip this step if you are SMD mounting.* |

If you are using pogo pins for the battery connector, place a pogo pin through the below marked hole and then solder it into place from the other side.

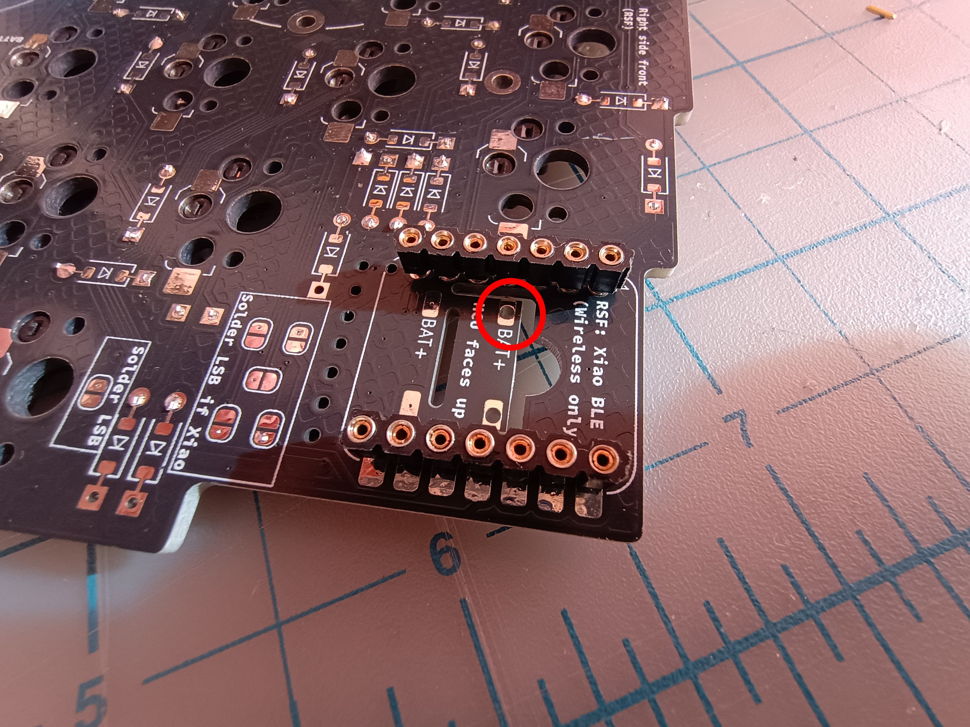
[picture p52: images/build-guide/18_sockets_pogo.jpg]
| |
| :--: |
| *Pogo pin goes here. You can replace the XIAO once this is done. This should *not* be mirrored on the other side, doublecheck where the B+ pad is located if you are uncertain.* |

For all other mounting approaches, I recommend using a diode leg. First, apply a bit of electrical tape to the XIAO's B- pad. This is to avoid shorting B+ and B-.

|solder legs |
| :--: |
| *Tape covers up B-.* |

Next, take one of your spare diode legs that you clipped off and solder it to the B+ pad.

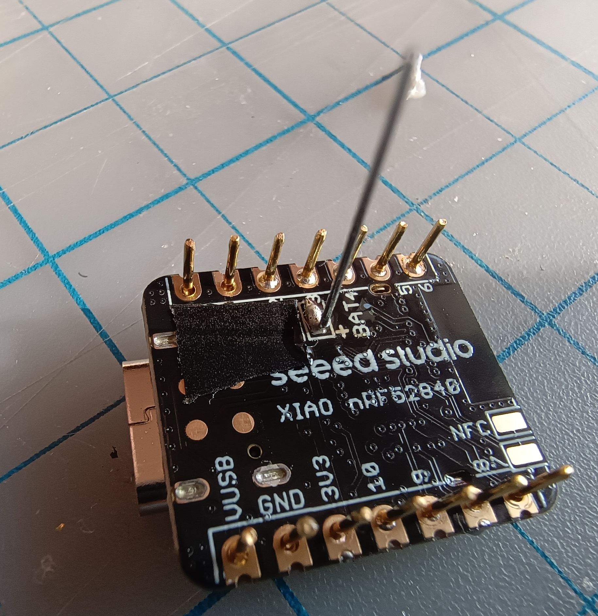
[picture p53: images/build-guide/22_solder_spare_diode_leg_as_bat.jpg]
solder legs
| |
| :--: |
| *Curved bit goes towards MCU, it's easier that way.* |

Going back to the PCB, snap off this little tab using a pair of pliers or similar:

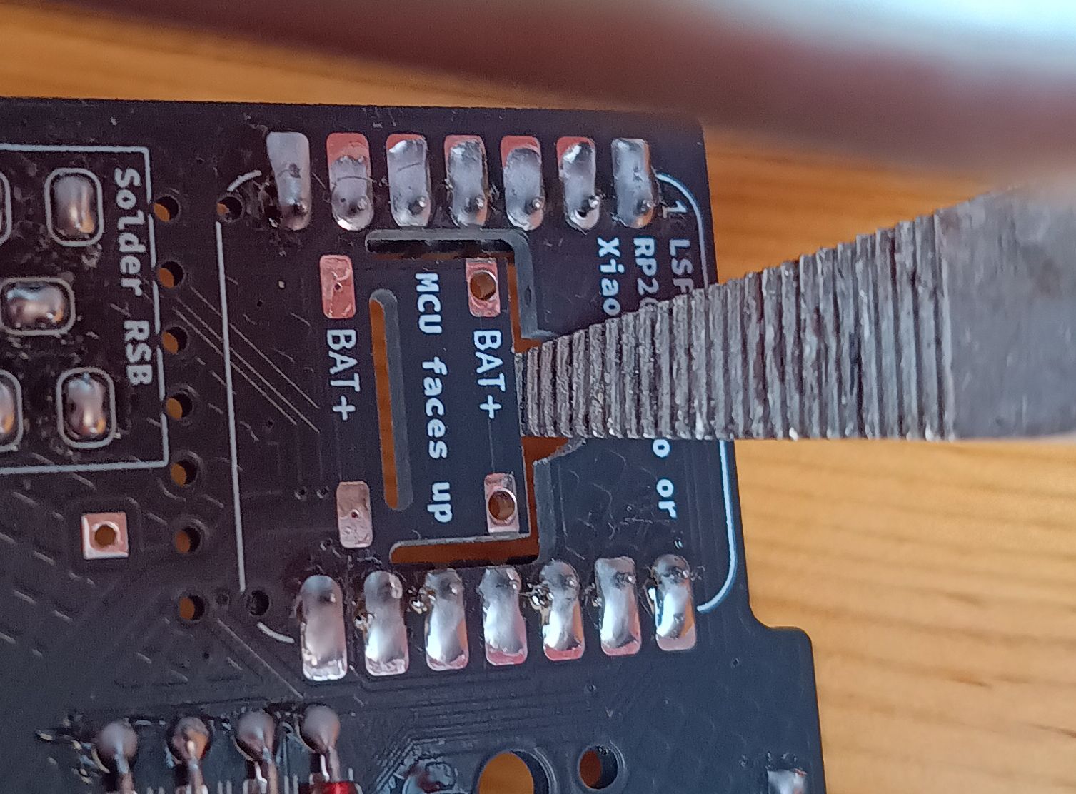
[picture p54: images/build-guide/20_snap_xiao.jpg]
| |
| :--: |
| *Snap this off* |

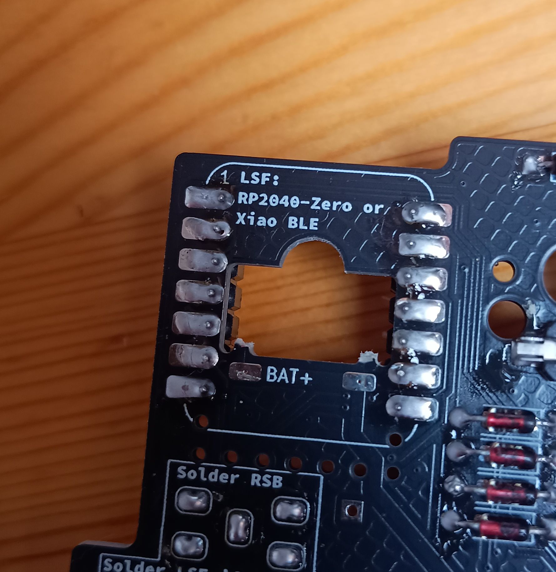
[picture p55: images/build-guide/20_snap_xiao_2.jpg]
| |
| :--: |
| *Resulting hole* |

Insert your MCU back into the sockets. The diode leg should stick out through the hole. You can then solder it to either of the spare B+ pads, clipping off the excess leg.

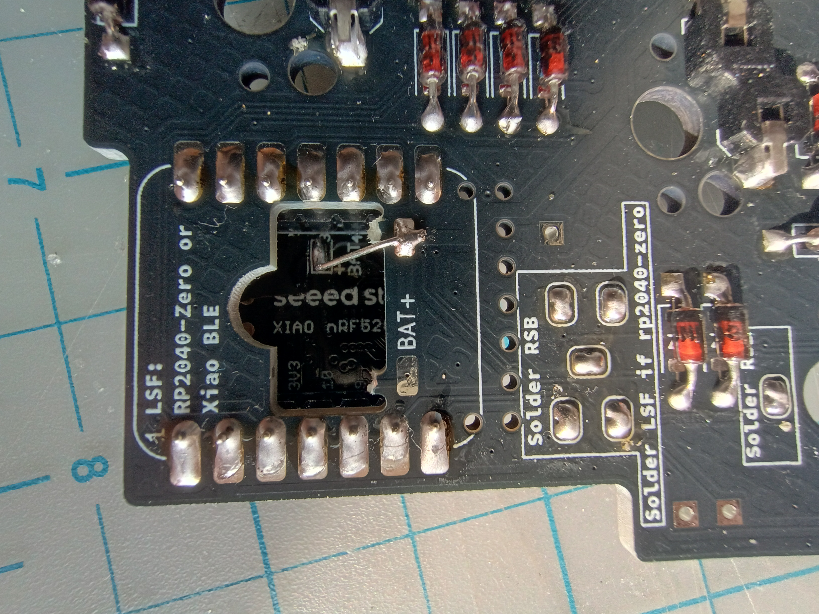
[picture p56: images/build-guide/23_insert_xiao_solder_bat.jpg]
solder legs
| |
| :--: |
| *Soldered diode leg.* |

If you ever need to swap the MCU, just cut the diode leg in half first. You should have *plenty* of spares.

# Optional: Thumb Cluster

If you want to move the thumb cluster, simply snap it off and then solder wires to the marked holes. The wires should all be parallel, no crossing between them.

Make sure you solder so that the wires are on back of the PCB, the same side as the hotswap sockets. 

# Finished

You're essentially done now, barring the insertion of switches into the hotswap sockets. You can continue by [following the case guide](../case.md) to build your case, or proceed straight to [firmware](https://github.com/Nick-Munnich/zmk-apiaster-module) to get it up and running.

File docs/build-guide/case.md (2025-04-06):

# Case Assembly Guide

Assembling the case is relatively simple, but there are a few finnicky parts. Your first task is XIAO exclusive - RP2040-Zero users can skip to the next step.

## XIAO Button

First, take the tray (with all the switch holes cut into it) You'll need to insert the button such that you can press it from the outside. This is very fiddly, you will definitely want to use tweezers.

|Button on top of tray |
| :--: |
| *Here's the little button lying on the MCU shell* |

|Button inserted from the top |
| :--: |
| *Insert the button from the top and wiggle it around to make sure it fits nicely and moves.* |

|Button inserted |
| :--: |
| *Insert the button into place. Very fiddly.* |

## Nuts

Insert the nuts into the tray. There should be 6 nuts. Keep the tray facing the the same way so that the nuts and the button don't fall out.

|Nuts inserted |
| :--: |
| *All the nuts inserted into place and flush.* |

## PCB

Place the PCB onto the tray. Do not turn the tray over, you're sandwiching the nuts into place between the PCB and tray.

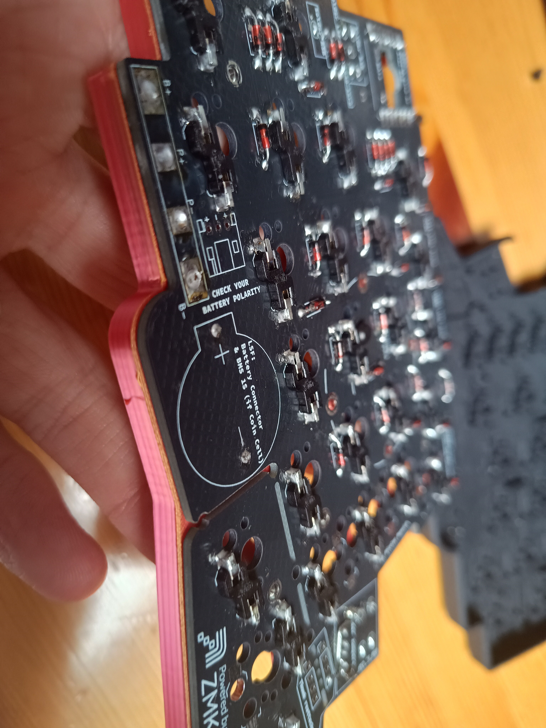
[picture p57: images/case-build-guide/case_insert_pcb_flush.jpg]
PCB inserted
| |
| :--: |
| *PCB should lie flush on the tray.* |

|Switch inserted |
| :--: |
| *Insert a switch before turning it over to help keep everything in place.* |

## Frame

Place the resulting PCB+Tray into the frame, then turn it over. Screw in the screws, this can also be a bit tricky. Make sure to apply pressure from underneath so that the nut sits nicely and can bind with the screw. Finally, put the silicone bumpers into their slots.

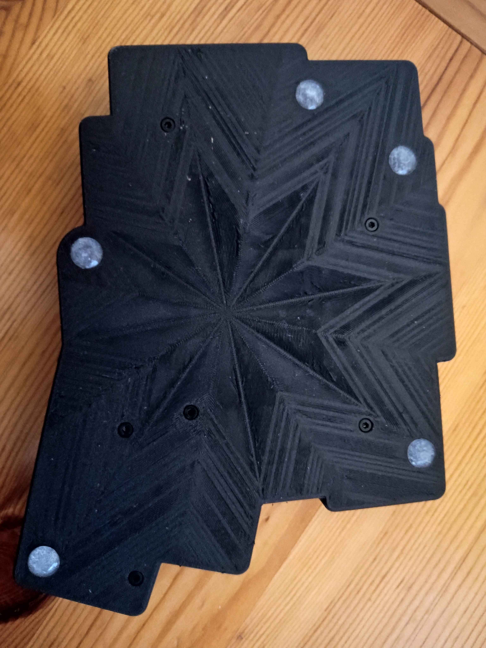
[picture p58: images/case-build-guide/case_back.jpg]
Backside inserted
| |
| :--: |
| *Everything should be nicely in place and secure.* |

If you have the XIAO and 1.75mm diameter transparent filament, insert some into the other hole by the MCU and then cut it flush (my tool of choice is nail clippers). You can optionally secure it in place with a tiny drop of super glue or similar. 

All done! 

I would like to request that you now take some images and share them, either publically somewhere or just as a GitHub issue. I'm preparing a gallery of Apiaster builds.

You can now go flash your [firmware](https://github.com/Nick-Munnich/zmk-apiaster-module).

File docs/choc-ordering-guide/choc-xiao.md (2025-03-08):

# Ordering List

You have made the big choices. There are still some minor choices to make, though, but these will be presented here. 

The links chosen are mostly from Aliexpress to take advantage of shipping. Other sources are available for all of these if you do some digging. If ordering from Aliexpress with price as a limiting factor, you *might* be able to find some of these for cheaper by taking advantage of their "bundle deals".

## PCB

At the moment, the go-to for price for PCB manufacturing is JLCPCB. You will need to download this "gerber" file: [Click to navigate to file](../../pcb/apiaster-choc/production/Apiaster_V1.zip).

Download Gerber

Once you have it, go to [JLCPCB](https://jlcpcb.com/).

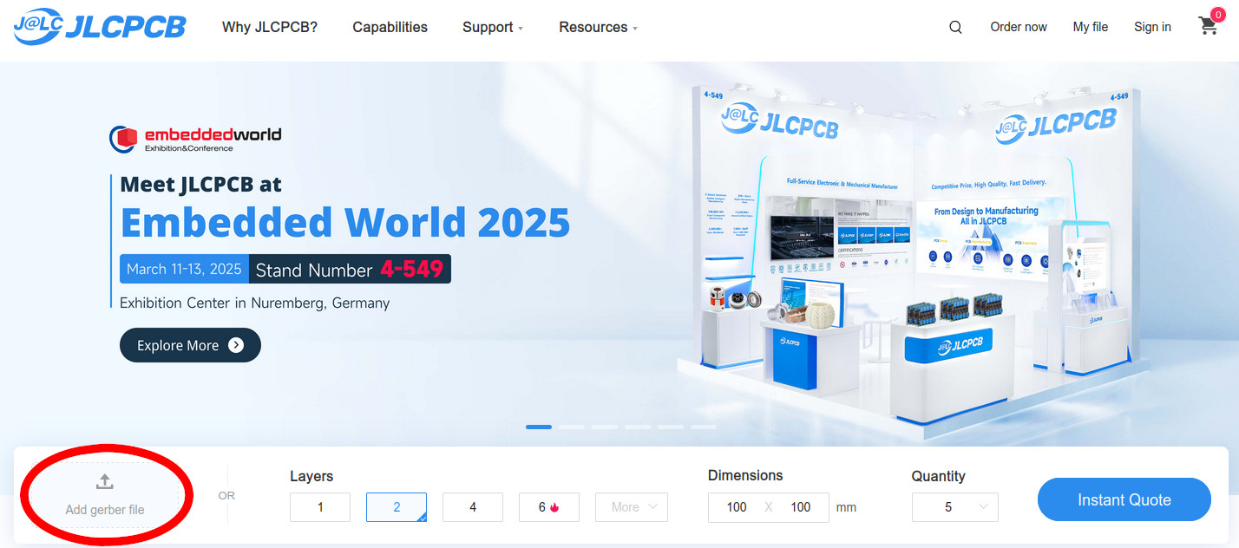
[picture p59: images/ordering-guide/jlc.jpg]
JLCPCB
 

Click on "Add Gerber File" and select the file you just downloaded (or drag and drop). You can in general leave all options as the default, but there are three you may wish to change:
 * PCB Color, an aesthetic choice. Pick your favorite.
 * Surface finish: I recommend Lead-free HASL for health and environmental reasons. Leaded HASL is best to pair with leaded solder and vice versa. ENIG looks fancy, but is pricy and entirely unnecessary for this board. Note that some combinations of surface finish + color may incur increased prices/build times. Lead-free HASL will incease the price slightly.
 * Mark on PCB: By default JLC includes a serial number, you can remove the number at no cost (this wasn't always the case, check if the price changes).

**Minimum price at time of writing, not including shipping, taxes, customs, etc:  $10.60**

## Mandatory Components

| Item | Amount | Link | Price (at time of writing)|Notes|
|---|---|---|---|----|
|1N4148 Diodes|70|https://www.aliexpress.com/item/4000142272546.html|$1.33 per 100|You can choose *either* these or the below ones, depending on what you prefer (these are easier for beginners).|
|1N4148S Diodes|70|https://www.aliexpress.com/item/1005005707644429.html|$1.03 per 100|These result in a slightly shorter case. Pick SOD123, not SOD323.|
|Choc Switches|50|[Assuming Choc V1 Pro Red](https://www.aliexpress.us/item/3256806440445666.html)|$29.05 for 70|As discussed previously.|
|Choc Keycaps|50|[Assuming Tai-Hai Thins](https://www.aliexpress.us/item/3256807292421547.html)|$40.81 for the set|As discussed previously. Note that the linked set does not have 1.5u keycaps, nor do I know of any 1.5u *vertically oriented* choc V1 keycaps that you can obtain without 3d printing. Choc blanks or Choc V2 keycap sets are *much* cheaper, but Choc V2 switches are more expensive. I would pick Choc V2, personally.|
|Hotswap Sockets|50|https://www.aliexpress.com/item/1005007232040760.html|$4.25 for 70| Make sure you're getting the shape suitable for Choc.|
|XIAO nRF52840|1-3|[Singles](https://www.seeedstudio.com/Seeed-XIAO-BLE-nRF52840-p-5201.html) or  [3-pack](https://www.seeedstudio.com/Seeed-Studio-XIAO-nRF52840-3PCS-p-5921.html)|$9.90 each or $23.39 for 3.| As discussed previously. A "sense" version is also sold, but *entirely* unnecessary and just increases the price.|

If you're only using one XIAO, you will also need:

| Item | Amount | Link | Price (at time of writing)|Notes|
|---|---|---|---|----|
|USB-A 3.0 female connector|2|https://de.aliexpress.com/item/1005003729287891.html|$1.08 for 5|Pick the "90 degree warped mouth".|
|USB-A 3.0 cable|1|https://de.aliexpress.com/item/1005001560424564.html|$2.03 each|As mentioned, you can purchase the parts for a custom cable instead.|

You will also need batteries. Your choice is between a coin cell battery, and a LiPo:

| Item | Amount | Link | Price (at time of writing)| Type | Notes|
|---|---|---|---|----|----|
|Coin Cell|2|https://www.amazon.de/-/en/LIR2032H-Rechargeable-Battery-Charger-Lithium/dp/B08HRY4QRL|€9.69 for 4|Coin Cell|The code is "LIR2032H", any product with that should be correct unless dubious.|
|LiPo Battery|2|https://www.aliexpress.us/item/2251832478677289.html|€3.93 each|LiPo|A somewhat trustworthy source on Aliexpress. Alleged capacity of 100mAh. Make sure you pick "JST PH 2.0MM" as a connector.|
|LiPo Battery|2|https://bihuade.com/products/37v-140mah-501522-liter-energy-battery-polymer-lithium-ion-li-ion-battery-for-smart-watchblue-toothgps-speaker|€3.93 each|LiPo|The biggest battery that fits in the designed case (fine-tuning may allow a bigger battery). Reliably sourced directly from the manufacturer, but beware the shipping costs. Make sure you pick "JST PH 2.0MM" as a connector.|
|Coin Cell holder|2|https://de.aliexpress.com/item/1005007339595580.html|$1.51 for 10|Coin Cell|Identical product can be found from multiple sources.|
|BMS 1S|2|https://www.aliexpress.com/item/1005007047240735.html|$1.11 for 10|Coin Cell|Needed to protect the coin cell from overcharge/overdischarge (LiPo should have this built in). Identical product can be found from multiple sources.|
|JST PH 2 pin|2|https://de.aliexpress.com/item/1005004955655144.html|$1.12 for 100|LiPo|Pick the right angle version. You can also pick a 3 pin version.|

A *lot* of LiPo battery sources, especially on Aliexpress, are dubious. They tend to claim battery capacities far beyond the actual capacity, often ship lacking proper protection, and there is no way to tell if they might not explode in the future. The shops I linked are ones that I have had good experiences with.

The main advantage of the coin cell is in its availability and reliability. The main advantage of LiPo is in its capacity. Use the [ZMK Power Profiler](https://zmk.dev/power-profiler) to estimate your battery life (LIR2032H has 70mAh):
 * The nice!nano is a decent approximation of the XIAO's battery consumption
 * If you use a cable between halves then do not enable the "split keyboard" toggle
 * If you use a dongle, then both your halves will have "peripheral" levels of power consumption, and the dongle will have "central" levels of power consumption (but should be connected via USB so that's irrelevant).

 I recommend the [prospector](https://github.com/carrefinho/prospector) if you want a fancy dongle, but a bare XIAO with nothing attached to it also works.

**Total minimum component cost at time of writing, not including shipping, customs, tariffs, etc.:  $41.63**

Obviously shipping, customs, taxes, and tariffs may still need to be considered and can vary wildly depending on your location.

## Recommended Components

The following parts are optional, but *highly* recommended:

| Item | Amount | Link | Price (at time of writing) |Notes|
|---|---|---|---|----|
|MCU round hole female sockets|2 7pin strips|https://www.aliexpress.com/item/32849903666.html|$1.41 for 5 40pin strips|You can easily snap off 7 pin lengths.|
|MCU square female sockets|2 7pin strips|https://www.aliexpress.com/item/4001198421663.html|$0.94 for 10  pin strips|These are *significantly* taller profile. I'm only listing them because they are slightly cheaper, I recommend the lower profile approach.|
|MCU round hole pins|14|https://www.aliexpress.com/item/32945586364.html|$0.96 for 4x5 or $1.35 for 4x20|You will be yanking the pins out from the plastic, make sure you have two pliers or similar for this purpose. I recommend buying the 20 piece 4 pin version.|
|Spare Wire|~50cm maybe?|https://www.aliexpress.com/item/4000580738993.html|$0.91 per coil| Used to reattach the thumb cluster if you want to move it. Also useful for bodge wires if you made a mistake.|
|Pogo Pins|2|https://www.aliexpress.us/item/3256805909678051.html|$2.62 for 10| Make sure the leg at the bottom is 0.8mm thick (or thinner), the overall height is at least 5mm, and the height when compressed is at most 4.5mm (assuming round hole sockets, heights may vary depending on your sockets). These are definitely optional, they are used for advanced socketing, but you can easily use a diode leg instead. Only recommended if you are using SMD diodes and don't have any spare wire.|

Socketing is very useful as insurance in case something breaks, it'll be much easier to test, fix, and replace if you can remove the MCU.

The round hole sockets with pins are recommended as they are lower profile. Square sockets can be used, but are bulkier and not quite as nice as a result - cheaper, though. For more information on the low profile socket approach, read through [this page](https://github.com/joric/nrfmicro/wiki/Sockets).

## Case Components

If you are ordering the included case design from somewhere (JLC is also a good source for this), then you should [obtain the case STL](../case.md) and order the case from whichever source you prefer.

The case was designed to be 3D printed with a layer height of 0.1mm. For FDM, this means a 0.2mm nozzle is ideal. If you are printing the case yourself with an FDM printer, this is your opportunity to purchase such a nozzle.

The following parts are necessary to build the included case design. Note that you can use the keyboard without a case, and you can also design your own case which may not need these parts. If you wish to move the thumb cluster, a case or additional structure of *some* kind is mandatory to secure it in place.

| Item | Amount | Link | Price (at time of writing) |Notes|
|---|---|---|---|----|
|6mm M2 sunk screws|12|https://www.aliexpress.com/item/4001199728978.html|$0.92 per 50|Make sure it's the 6mm version.|
|1.6mm tall M2 nuts|12|https://www.aliexpress.com/item/1005007593861199.html|$0.90 per 50|Select the M2 version.|
|8mm outer diameter, 2mm tall silicone bumpers|10|https://www.aliexpress.com/item/1005006382486165.html|$1.28 per 100|Make sure measurements match.|
|1.75mm diameter transparent filament|2cm or so|||Optional, for a light guide. Not worth buying a whole roll of filament for, ask around a bit.|

The case/pcb also allows for two different tenting options; Magsafe-style magnets and the SplitKB tenting puck. The below are optional components to use for this. Note that you can obtain cheaper tenting options via e.g. 3d printing, or with cheap phone stands, magsafe and the tenting puck are merely the options which allow for the most flexibility at the cost of price. **I have not tested these particular products in detail, they are merely those which I would pick myself if I had the desire**.

| Item | Amount | Link | Price (at time of writing)| Tenting Style |Notes| 
|---|---|---|---|----|----|
|Magsafe stickers|2|https://www.aliexpress.com/item/1005006994459890.html|$1.12 each|Magsafe||
|Tenting Puck|2|https://splitkb.com/products/tenting-puck|€34,94 for 2|Puck|SplitKB also sells very good, but expensive, tripods that can go on top of your table.|
|Clamp with 1/4" thread|2|https://www.aliexpress.com/item/1005005962644108.html|$6.44 each|Both| Clamp onto the side of your desk or onto your chair, the tenting puck will screw in while the magsafe stickers will need an adapter. The branded and more reliable version is from the brand "SMALLRIG". I've also personally had positive experiences with "NEEWER".|
|Magsafe 1/4" adapter|2|https://www.aliexpress.com/item/1005006074567830.html|$6.50 each|Magsafe||
|Magsafe Phone Stand|2|https://www.aliexpress.com/item/1005007052940305.html| $7.30 each|Magsafe| You really want one with a good wide stable base, otherwise it risks toppling.|

# Tools

You will *need* the following tools:
 * A soldering iron. You don't need to go *super* expensive with this, but I would avoid the incredibly cheap $2 soldering irons. That said, good quality solder is arguably more important than a good quality soldering iron. I use an older, pricier model off of Ebay. I've heard good things about the [pinecil](https://pine64.com/product/pinecil-smart-mini-portable-soldering-iron/) and [this option from Aliexpress](https://www.aliexpress.com/item/1005005196528703.html). Do some shopping around and researching for this option, if you cannot obtain access to one some other way.
 * Good quality solder. The ideal solder imo would be SAC305 lead-free solder wire, but it is on the expensive side so shop around a bit - aim for no-clean, lead-free at a lower melting point. If you find lead acceptable, decent leaded solder can be found for much cheaper. If you are using only SMD components, then I recommend some 217C lead-free solder paste. I found what I believe could be a decent choice [here](https://de.aliexpress.com/item/1005006956427027.html), but you will *need* [flux](https://www.aliexpress.com/item/1005006568158452.html) to go along with it, as it doesn't have any in its core (unlike most solder wire).
 * [Wire cutters](https://www.aliexpress.us/item/2251832814528613.html)

The following tools are highly recommended:
 * [Switch Puller](https://www.aliexpress.com/item/1005006675061450.html) 
 * [Multimeter](https://www.aliexpress.com/item/1005007009854702.html) (one with a continuity mode that beeps)
 * [Breadboard](https://www.aliexpress.com/item/1005007557572041.html)
 * [Flux](https://www.aliexpress.com/item/1005006568158452.html), either in pen or syringe form. This particular flux has not been tested by me, but I dislike the one that I have so I won't be recommending it. Get no-clean.
 * [Desoldering braid](https://www.aliexpress.com/item/1005007514789306.html)
 * [Spare wire](https://www.aliexpress.com/item/4000580738993.html) (also a recommended component)
 * [Silicone soldering mat](https://www.aliexpress.com/item/1005005472358780.html), to protect your working area.
 * [Precision tweezers](https://www.aliexpress.com/item/1005005589349988.html)
 * [Electrical tape](https://www.aliexpress.us/item/3256807167030448.html)
 * [Crocodile clips](https://www.aliexpress.us/item/2251832646004932.html)

 A multimeter is **crucial** for both troubleshooting and confirming that you did everything correctly. You can skip it if you love living on the edge, though.

 The crocodile clips are used to hold the BMS 1S to the PCB when soldering. If you are using a LiPo or have a spare third hand, they are unnecessary. The electrical tape is useful to cover up some pads to avoid shorts.

If you are in school or university, I would highly suggest that you check which resources your school can provide to you. Universities especially tend to have soldering equipment available for student use.

# Build Guide

[Click here to continue with the build guide](../build-guide/pcb.md).

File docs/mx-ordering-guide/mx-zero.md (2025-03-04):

# Ordering List

You have made the big choices. There are still some minor choices to make, though, but these will be presented here. 

The links chosen are mostly from Aliexpress to take advantage of shipping. Other sources are available for all of these if you do some digging. If ordering from Aliexpress with price as a limiting factor, you *might* be able to find some of these for cheaper by taking advantage of their "bundle deals".

## PCB

At the moment, the go-to for price for PCB manufacturing is JLCPCB. You will need to download this "gerber" file: [Click to navigate to file](../../pcb/apiaster-mx/production/Apiaster_V1.zip).

Download Gerber

Once you have it, go to [JLCPCB](https://jlcpcb.com/).

JLCPCB 

Click on "Add Gerber File" and select the file you just downloaded (or drag and drop). You can in general leave all options as the default, but there are three you may wish to change:
 * PCB Color, an aesthetic choice. Pick your favorite.
 * Surface finish: I recommend Lead-free HASL for health and environmental reasons. Leaded HASL is best to pair with leaded solder and vice versa. ENIG looks fancy, but is pricy and entirely unnecessary for this board. Note that some combinations of surface finish + color may incur increased prices/build times. Lead-free HASL will incease the price slightly.
 * Mark on PCB: By default JLC includes a serial number, you can remove the number at no cost (this wasn't always the case, check if the price changes).

**Minimum price at time of writing, not including shipping, taxes, customs, etc:  $10.60**

## Mandatory Components

| Item | Amount | Link | Price (at time of writing)|Notes|
|---|---|---|---|----|
|1N4148 Diodes|70|https://www.aliexpress.com/item/4000142272546.html|$1.33 per 100|You can choose *either* these or the below ones, depending on what you prefer (these are easier for beginners).|
|1N4148S Diodes|70|https://www.aliexpress.com/item/1005005707644429.html|$1.03 per 100|These result in a slightly shorter case. Pick SOD123, not SOD323.|
|MX Switches|50|[Assuming previous section's Outemu](https://www.aliexpress.com/item/1005007140434837.html)|$11.56 for 70|As discussed previously.|
|MX Keycaps|50|[Assuming previous section's cheap set](https://www.aliexpress.com/item/1005005386897424.html)|$3.42 for the set|As discussed previously.|
|Hotswap Sockets|50|https://www.aliexpress.com/item/1005007232040760.html|$3.63 for 70| Make sure you're getting the shape suitable for MX.|
|RP2040-Zero MCU|1|https://de.aliexpress.com/item/1005007650325892.html|$1.67 each|Get one *without* the sockets already soldered on.|
|USB-A 3.0 female connector|2|https://de.aliexpress.com/item/1005003729287891.html|$1.08 for 5|Pick the "90 degree warped mouth".|
|USB-A 3.0 cable|1|https://de.aliexpress.com/item/1005001560424564.html|$2.03 each|As mentioned, you can purchase the parts for a custom cable instead.|

**Total minimum component cost at time of writing, not including shipping, customs, tariffs, etc.:  $25.75**

Obviously shipping, customs, taxes, and tariffs may still need to be considered and can vary wildly depending on your location.

## Recommended Components

The following parts are optional, but *highly* recommended:

| Item | Amount | Link | Price (at time of writing) |Notes|
|---|---|---|---|----|
|MCU round hole female sockets|2 7pin strips|https://www.aliexpress.com/item/32849903666.html|$1.41 for 5 40pin strips|You can easily snap off 7 pin lengths.|
|MCU square female sockets|2 7pin strips|https://www.aliexpress.com/item/4001198421663.html|$0.94 for 10  pin strips|These are *significantly* taller profile. I'm only listing them because they are slightly cheaper, I recommend the lower profile approach.|
|MCU round hole pins|14|https://www.aliexpress.com/item/32945586364.html|$0.96 for 4x5 or $1.35 for 4x20|You will be yanking the pins out from the plastic, make sure you have two pliers or similar for this purpose. I recommend buying the 20 piece 4 pin version.|
|Spare Wire|~50cm maybe?|https://www.aliexpress.com/item/4000580738993.html|$0.91 per coil| Used to reattach the thumb cluster if you want to move it. Also useful for bodge wires if you made a mistake.|

The RP2040-Zero comes with a socket that *can* be soldered to the PCB directly, but using proper sockets is highly recommended. These will allow you to remove the MCU from the PCB, allowing you to upgrade to a XIAO nRF52840 in the future if you ever so desire. **You will find it almost impossible to upgrade without socketing**. It also serves as insurance in case something breaks, it'll be much easier to test, fix, and replace if you can remove the MCU.

The round hole sockets with pins are recommended as they are lower profile. Square sockets can be used, but are bulkier and not quite as nice as a result - cheaper, though. For more information on the low profile socket approach, read through [this page](https://github.com/joric/nrfmicro/wiki/Sockets).

## Case Components

If you are ordering the included case design from somewhere (JLC is also a good source for this), then you should [obtain the case STL](../case.md) and order the case from whichever source you prefer.

The case was designed to be 3D printed with a layer height of 0.1mm. For FDM, this means a 0.2mm nozzle is ideal. If you are printing the case yourself with an FDM printer, this is your opportunity to purchase such a nozzle.

The following parts are necessary to build the included case design. Note that you can use the keyboard without a case, and you can also design your own case which may not need these parts. If you wish to move the thumb cluster, a case or additional structure of *some* kind is mandatory to secure it in place.

| Item | Amount | Link | Price (at time of writing) |Notes|
|---|---|---|---|----|
|6mm M2 sunk screws|12|https://www.aliexpress.com/item/4001199728978.html|$0.92 per 50|Make sure it's the 6mm version.|
|1.6mm tall M2 nuts|12|https://www.aliexpress.com/item/1005007593861199.html|$0.90 per 50|Select the M2 version.|
|8mm outer diameter, 2mm tall silicone bumpers|10|https://www.aliexpress.com/item/1005006382486165.html|$1.28 per 100|Make sure measurements match.|

The case/pcb also allows for two different tenting options; Magsafe-style magnets and the SplitKB tenting puck. The below are optional components to use for this. Note that you can obtain cheaper tenting options via e.g. 3d printing, or with cheap phone stands, magsafe and the tenting puck are merely the options which allow for the most flexibility at the cost of price. **I have not tested these particular products in detail, they are merely those which I would pick myself if I had the desire**.

| Item | Amount | Link | Price (at time of writing)| Tenting Style |Notes| 
|---|---|---|---|----|----|
|Magsafe stickers|2|https://www.aliexpress.com/item/1005006994459890.html|$1.12 each|Magsafe||
|Tenting Puck|2|https://splitkb.com/products/tenting-puck|€34,94 for 2|Puck|SplitKB also sells very good, but expensive, tripods that can go on top of your table.|
|Clamp with 1/4" thread|2|https://www.aliexpress.com/item/1005005962644108.html|$6.44 each|Both| Clamp onto the side of your desk or onto your chair, the tenting puck will screw in while the magsafe stickers will need an adapter. The branded and more reliable version is from the brand "SMALLRIG". I've also personally had positive experiences with "NEEWER".|
|Magsafe 1/4" adapter|2|https://www.aliexpress.com/item/1005006074567830.html|$6.50 each|Magsafe||
|Magsafe Phone Stand|2|https://www.aliexpress.com/item/1005007052940305.html| $7.30 each|Magsafe| You really want one with a good wide stable base, otherwise it risks toppling.|

# Tools

You will *need* the following tools:
 * A soldering iron. You don't need to go *super* expensive with this, but I would avoid the incredibly cheap $2 soldering irons. That said, good quality solder is arguably more important than a good quality soldering iron. I use an older, pricier model off of Ebay. I've heard good things about the [pinecil](https://pine64.com/product/pinecil-smart-mini-portable-soldering-iron/) and [this option from Aliexpress](https://www.aliexpress.com/item/1005005196528703.html). Do some shopping around and researching for this option, if you cannot obtain access to one some other way.
 * Good quality solder. The ideal solder imo would be SAC305 lead-free solder wire, but it is on the expensive side so shop around a bit - aim for no-clean, lead-free at a lower melting point. If you find lead acceptable, decent leaded solder can be found for much cheaper. If you are using only SMD components, then I recommend some 217C lead-free solder paste. I found what I believe could be a decent choice [here](https://de.aliexpress.com/item/1005006956427027.html), but you will *need* [flux](https://www.aliexpress.com/item/1005006568158452.html) to go along with it, as it doesn't have any in its core (unlike most solder wire).
 * [Wire cutters](https://www.aliexpress.us/item/2251832814528613.html)

The following tools are highly recommended:
 * [Switch Puller](https://www.aliexpress.com/item/1005006675061450.html) 
 * [Multimeter](https://www.aliexpress.com/item/1005007009854702.html) (one with a continuity mode that beeps)
 * [Breadboard](https://www.aliexpress.com/item/1005007557572041.html)
 * [Flux](https://www.aliexpress.com/item/1005006568158452.html), either in pen or syringe form. This particular flux has not been tested by me, but I dislike the one that I have so I won't be recommending it. Get no-clean.
 * [Desoldering braid](https://www.aliexpress.com/item/1005007514789306.html)
 * [Spare wire](https://www.aliexpress.com/item/4000580738993.html) (also a recommended component)
 * [Silicone soldering mat](https://www.aliexpress.com/item/1005005472358780.html), to protect your working area.
 * [Precision tweezers](https://www.aliexpress.com/item/1005005589349988.html)

 A multimeter is **crucial** for both troubleshooting and confirming that you did everything correctly. You can skip it if you love living on the edge, though.

If you are in school or university, I would highly suggest that you check which resources your school can provide to you. Universities especially tend to have soldering equipment available for student use.

# Build Guide

[Click here to continue with the build guide](../build-guide/pcb.md).

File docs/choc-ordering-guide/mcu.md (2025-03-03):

# Choice #2: MCU

Your next choice is for the MCU of your keyboard, i.e. the brain that interprets key presses to identify what to send to the host device.

**Note that if you socket your MCU, as I recommend and demonstrate in this guide, you will be able to switch out the MCU with an "upgrade" at a later point in time.**

Here are your options:

|MCU|Price|Amount|Wireless|Notes|
|----|----|----|----|----|
|[RP2040-Zero](https://de.aliexpress.com/item/1005007650325892.html)|~$2-3 each|1| No | Both halves are connected with a USB A 3.0 cable, and the keyboard is connected to the host with a USB C cable.|
|[XIAO nRF52840](https://www.seeedstudio.com/Seeed-XIAO-BLE-nRF52840-p-5201.html)|~$10-12 each|1|Yes|Both halves are connected with a USB A 3.0 cable, the keyboard can be connected to the host via either Bluetooth or with a USB C cable.|
|[XIAO nRF52840](https://www.seeedstudio.com/Seeed-XIAO-BLE-nRF52840-p-5201.html)|~$10-12 each|2|Yes|The halves are connected via Bluetooth, the keyboard can be connected to the host via either Bluetooth or with a USB C cable going to a *prespecified* half.|
|[XIAO nRF52840 (different link)](https://www.seeedstudio.com/Seeed-Studio-XIAO-nRF52840-3PCS-p-5921.html)|$18-23|3|Yes| A set of 3 can be bought for \$23. Seeed currently offers a \$5 discount to first time signups to their newsletter. The third MCU is used as a dongle, significantly increasing the battery life when compared to having two XIAO controllers (but no difference when compared to only one with the halves connected via USB A 3.0)|

Even if you purchase and install multiple XIAOs, you can revert to using only one with little hassle.

Please click the links to doublecheck the prices for your region, as shipping and taxes may cause these to vary. If your choice involves a USB A 3.0 cable, you will also need to purchase (if you don't already have them) a USB A 3.0 cable and a set of USB 3.0 female connectors:

|Item|Amount|Notes|
|----|---- |----|
|[USB-A 3.0 Cable](https://de.aliexpress.com/item/1005001560424564.html)|1| A braided cable is recommended. Make sure you select a USB 3.0 cable, the linked store also sells USB 2.0 "color", which is useless.|
|[USB-A 3.0 Female Connectors](https://de.aliexpress.com/item/1005003729287891.html)|2|Sold in sets of 5. Pick the "90 degree warped mouth".|

If you're feeling *really* fancy, you could also make your own USB A 3.0 cable with a custom length & shaping using [these end pieces](https://www.aliexpress.com/item/4001266047327.html). An (untested) guide on this can be found [here](../custom-usb-cable.md).

[Continue with the RP2040-Zero.](./choc-zero.md)

[Continue with the XIAO nRF52840.](./choc-xiao.md)

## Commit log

2025-03-03 Making case with build123d
    [Kailh_PG1353.STEP, XIAO-nRF52840 v15.step, apiaster-left-tray.stl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]
2025-03-03 README and ordering guide completed.
    [apiaster-left-trayrpi-mx-for-witch.stl, bom.csv, designators.csv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]
2025-03-04 PCB build guide.
2025-03-04 Case documentation
2025-03-04 Pre-generated cases
    [apiaster-left-frame_mx-zero-reduced-inner-classic-thumbs.stl, apiaster-left-frame_mx-zero-reduced-inner-ripple-thumbs.stl, apiaster-left-tray.stl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]
2025-03-04 Custom USB cable
2025-03-08 rename premade stls and update choc xiao build page
    [apiaster-l-bot-rp-red-inner-classic-thmb.stl, apiaster-l-bot-rp-red-inner-ripple-thmb.stl, apiaster-l-top-nrf-coin-all-inner-classic-thmb.stl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]
2025-03-12 bugfix and witch cases
    [apiaster-left-framewitch-mx-lipo-xiao-inred-clstmb.stl, apiaster-left-framewitch-mx-lipo-xiao-inred-riptmb.stl, apiaster-left-traywitch-choc-coin-xiao-flex.stl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]
2025-03-24 added another request
    [apiaster-left-tray.stl, apiaster-right-tray.stl]
2025-03-27 fix bugs, package inconsistency (should be good with current defaults now)
2025-03-27 Fix lipo shell
2025-03-30 Extract STL export result to a variable, to avoid nested f-strings.
2025-05-25 Gha case (#16)
    * feat: Add gha to generate case
    * Fix inputs
2025-05-25 fix switch arg
2025-05-26 Document GitHub Action
    [apiaster-l-bot-rp-red-inner-classic-thmb.stl, apiaster-l-bot-rp-red-inner-ripple-thmb.stl, apiaster-l-top-nrf-coin-all-inner-classic-thmb.stl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]
2025-06-01 Update make_case.py
    Find & Replace all references of STL with STEP to try to export as step.
